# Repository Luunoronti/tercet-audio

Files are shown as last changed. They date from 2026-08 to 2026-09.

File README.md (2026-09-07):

# TERCET

Trzyczęściowy, w pełni analogowy lampowy tor audio DIY — trzy urządzenia
w spójnej serii (drewno + lustrzana stal nierdzewna + żarzenie lamp):

1. **`riaa/`** — przedwzmacniacz gramofonowy RIAA (stereo).
   2× ECC83 + ECC82 (wtórnik katodowy), pasywna korekcja 3180/318/75 µs,
   B+ rozdzielone per kanał, dławik w filtrze, automatyczne rozładowanie
   kondensatorów, wyciszanie wyjść z opóźnieniem, ground breaker GND/PE.
   **Stan: schemat rev E — gotowy do budowy.**
2. **`power-amp/`** — lampowa końcówka mocy z regulacją głośności
   i analogowymi wskaźnikami wychyłowymi. *Stan: planowanie.*
3. **`preamp/`** — przedwzmacniacz liniowy: selektor wejść, głośność,
   balans, mono, filtry, barwa. *Stan: planowanie.*

Poza serią: **`headamp/`** — lampowy wzmacniacz słuchawkowy SE EL84
pod DT 770 M (stan: schemat poglądowy + symulacje; patrz
`docs/PROJEKT-HEADAMP.md`).

Pozostałe katalogi: **`common/`** — bloki współdzielone między urządzeniami
(żarzenie DC z LD1085, automatyka rozładowania/mute), **`enclosure/`** —
pliki obudów (DXF płyt pod cięcie laserowe, grawer frontów),
**`docs/`** — dokument ustaleń projektu (`PROJEKT-RIAA.md` = "pamięć"
projektu; przy pracy z AI podawać ten plik na starcie sesji).

## Jak pracujemy z plikami KiCada

Schematy są **generowane skryptem**: `riaa/gen.py` (+ `symlib.py`) buduje
`riaa_preamp.kicad_sch` od zera, z symbolami osadzonymi w pliku (otwiera się
w KiCadzie 7+ bez zewnętrznych bibliotek). Weryfikacja: `check.py` eksportuje
netlistę przez `kicad-cli` i sprawdza ~60 asercji połączeń (w tym rozdział
masy sygnałowej od PE i separację kanałów).

```
cd riaa
python3 gen.py
kicad-cli sch export netlist -o riaa.net riaa_preamp.kicad_sch
python3 check.py
kicad-cli sch export pdf -o riaa_preamp.pdf riaa_preamp.kicad_sch
```

Zmiany koncepcyjne robimy w `gen.py` i regenerujemy; drobne poprawki ręczne
w Eeschema są OK, ale wtedy plik `.kicad_sch` staje się źródłem prawdy —
odnotować w commicie. Etap PCB: planowany interaktywnie przez wtyczkę
Konnect (KiCad 10 + MCP).

## Bezpieczeństwo

W urządzeniach występują napięcia do ~330 V DC — śmiertelnie niebezpieczne.
Zasady (PE, ground breaker, rozładowanie, pomiar przed pracą) opisane
w `docs/PROJEKT-RIAA.md` i na schematach. Budujesz na własną
odpowiedzialność.

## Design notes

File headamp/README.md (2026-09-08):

# headamp — lampowy wzmacniacz słuchawkowy (SE EL84)

Czwarte urządzenie serii (poza kanonicznym "tercetem"): biurkowy wzmacniacz
słuchawkowy pod Beyerdynamic DT 770 M (80 Ω), źródło: DAC (E-MU 0202 USB,
wyjście liniowe). W torze sygnałowym wyłącznie lampy i transformatory.

**Topologia (na kanał):** ½ ECC82 (wspólna katoda) → RC → EL84 w triodzie
(g2→a przez 100R) → transformator SE 5k:80 Ω. Bez globalnego NFB.
B+ ~300 V (CLC), żarzenie DC + elewacja +50 V — blok wspólny, patrz
`common/` (LD1085, identyczny jak w RIAA).

**Przełączniki charakteru (oba czysto pasywne):**
- **S1 (DPDT)** — crossfeed między DAC a potencjometrem: bas −14 dB do
  przeciwnego kanału, wygasa >~700 Hz; scena "z kolumn".
- **S2 (DPST)** — "wokal do przodu": odłącza C2b 100µ przy katodzie drivera
  (zostaje 1µ) → półka −3 dB poniżej ~200 Hz.

**Wyniki symulacji** (ngspice, modele Korena; `sim/`):
wzmocnienie 24,7 dB @1 kHz; pasmo −3 dB: 24 Hz…>100 kHz (dół ograniczony
Lp OPT=15 H — zamówić ≥25 H); Zout ~36 Ω; THD @0,6 Vrms: 0,20%
(niemal czysta H2, H3 −87 dB); EL84: 285 V / 29 mA (8,2 W).

Szczegóły i log decyzji: `docs/PROJEKT-HEADAMP.md`.

## Pliki
- `gen.py` — generator schematu KiCad (`headamp.kicad_sch`); **źródło
  prawdy jest w tym pliku, NIE edytować schematu ręcznie w Eeschema**
  (regeneracja go nadpisze). UUID deterministyczne (uuid5) — dwa
  uruchomienia dają identyczny plik. Layout w ramkach modułów (WEJŚCIE,
  KANAŁ L, KANAŁ P, WYJŚCIE, SIEĆ, ZASILACZ B+, ŻARZENIE); połączenia
  między modułami drutami (nie global_label), poza ELEV (etykieta
  lokalna, tam gdzie łączy dzielnik elewacji z blokiem żarzenia) i GND/PE
  (symbole power). Żarniki lamp (ECC82 U1 unit3, EL84 U2/U202 unit2)
  narysowane wewnątrz ramki ŻARZENIE, połączone drutami z wyjściem
  LD1085 i z minusem żarzenia (= ELEV).
- `symlib.py` — parser symboli KiCad (kopia `riaa/symlib.py`, inna
  ścieżka domyślna biblioteki: Windows).
- `check.py` — asercje netlisty (wzór `riaa/check.py`): kanał L, kanał
  P (funkcja `chan()` parametryzowana referencjami), zasilacz, crossfeed
  S1, gniazda WE/WY.
- `sim/amp.cir` — pełny tor (driver + końcówka + OPT), .op / .ac / THD
- `sim/crossfeed.cir` — sieć crossfeedu S1, wariant "ON" (bez przełącznika,
  same wartości R/C) - historyczny, poprzednik `crossfeed_sw.cir`.
- `sim/crossfeed_sw.cir` — **źródło prawdy** dla topologii narysowanej w
  `gen.py` (SW401 na WYJŚCIU galęzi krzyżowej, DECYZJA 2026-09-08 - patrz
  docs/PROJEKT-HEADAMP.md). Trzy warianty w jednym pliku (ngspice batch,
  kolejne `.end`): 1) ON (krzyżowy załączony), 2) OFF nowa topologia
  (S1 na wyjściu - odłącza całą galąź krzyżową od wyjść), 3) OFF stara
  topologia (S1 na wejściu, ODRZUCONA - R405/R406+C403/C404 nadal
  obciążają wyjścia, ugięcie basu ~1,4 dB - uzasadnienie zmiany).
- `ref/headamp.pdf` — eksport aktualnego schematu (`kicad-cli sch export
  pdf`), regenerowany po każdej zmianie i commitowany razem z
  `headamp.kicad_sch` (patrz Workflow niżej).
- `ref/se_el84.svg`, `ref/crossfeed.svg` — schematy poglądowe (schemdraw,
  historyczne, przed generatorem)
- `layout/layout_top.py` — generator (matplotlib, bez KiCada) propozycji
  **rozmieszczenia elementów w obudowie** (rzut z góry, 260×200 mm, skala
  1:1 — zmniejszone 2026-09-08 z pierwotnych 300×250, patrz
  docs/PROJEKT-HEADAMP.md) → `ref/layout_top.svg`/`.png`. Zasilacz na
  chassis (górnej płycie) tylko jako bryły T301/L1/J1+F1/SW1/NE1; reszta
  zasilacza na **PCB** (DECYZJA, nie powietrznie — patrz
  docs/PROJEKT-HEADAMP.md) w zarezerwowanej strefie pod płytą. Montaż
  powietrzny toru audio: listwy lutownicze + elementy na nóżkach
  podstawek lamp — szczegółowy przydział w `ref/layout_bom_montaz.md`.
- `ref/layout_bom_montaz.md` — tabela przydziału elementów toru audio:
  na nóżkach podstawek lamp vs listwy lutownicze A/B_L/B_P/D, z numerami
  pinów (ECC82/EL84) i uzasadnieniem.

## Projekt roboczy (edycja ręczna)
`kicad/headamp.kicad_pro` + `kicad/headamp.kicad_sch` — kopia schematu
wygenerowanego niżej (netlista równoważna, DECYZJA 2026-09-08), z
nowym uuid arkusza. To jest **plik roboczy edytowany ręcznie w Eeschema
przez użytkownika** (bez MCP Konnect); `gen.py`/`headamp.kicad_sch` w tym
katalogu (`headamp/`) to od teraz archiwalny pierwowzór, nie rozwijany
dalej. Workflow weryfikacji po edycji `kicad/headamp.kicad_sch`:
```
kicad-cli sch export netlist --format kicadsexpr -o headamp/kicad/headamp.net headamp/kicad/headamp.kicad_sch
python headamp/check.py headamp/kicad/headamp.net
kicad-cli sch erc --format json --severity-all -o headamp/kicad/erc.json headamp/kicad/headamp.kicad_sch
kicad-cli sch export pdf -o headamp/ref/headamp_kicad.pdf headamp/kicad/headamp.kicad_sch
```
Oczekiwane: check.py OK; ERC 0/0. Szczegóły: docs/PROJEKT-HEADAMP.md,
CLAUDE.md.

## Workflow (regeneracja schematu, archiwalne gen.py)
```
python headamp/gen.py
kicad-cli sch export netlist --format kicadsexpr -o headamp/headamp.net headamp/headamp.kicad_sch
python headamp/check.py
kicad-cli sch erc --format json --severity-all -o erc.json headamp/headamp.kicad_sch
kicad-cli sch export pdf -o headamp/ref/headamp.pdf headamp/headamp.kicad_sch
```
Oczekiwane: check.py OK; **ERC = 0 błędów, 0 ostrzeżeń**. Ostatni krok
(PDF do `headamp/ref/`) wykonać po każdej zmianie schematu i obejrzeć
wynik - `headamp/ref/headamp.pdf` jest commitowany razem z
`headamp.kicad_sch` (nie jest ignorowany, mimo że `.gitignore` wycina
`headamp/*.pdf` gdzie indziej). Szczegóły i log decyzji:
docs/PROJEKT-HEADAMP.md.

## Uruchomienie symulacji
```
cd headamp/sim
ngspice -b amp.cir
ngspice -b crossfeed_sw.cir
```

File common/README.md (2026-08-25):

# common — bloki współdzielone serii TERCET

Bloki projektowane z myślą o reużyciu we wszystkich trzech urządzeniach
(na razie opisane w schemacie RIAA; przy końcówce mocy wydzielimy je tu
jako wspólne moduły/PCB):

- **Żarzenie DC**: uzwojenie ~7 V → mostek Schottky (1N5822) → 10000 µF →
  LDO LD1085 → 6,3 V DC, z elewacją do +50 V (dzielnik z B+).
- **Automatyka**: K1 — rozładowanie kondensatorów po zaniku sieci
  (styk NC + rezystor mocy); K2/K3 — wyciszanie wyjść z opóźnieniem
  (2N7000 + RC), natychmiastowy mute przy wyłączeniu.
- **Ground breaker**: 10R/5W ∥ 2× 1N5408 antyrównolegle ∥ 100n —
  jedyny punkt styku masy sygnałowej z chassis/PE.
- **Wejście sieciowe**: IEC + bezpiecznik → wyłącznik DPST → NTC →
  transformator; warystor; neonówka jako kontrolka.

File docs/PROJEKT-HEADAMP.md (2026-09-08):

# PROJEKT-HEADAMP — pamięć projektu wzmacniacza słuchawkowego

Dokument ustaleń, analogicznie do PROJEKT-RIAA.md. Przy pracy z AI podawać
ten plik na starcie sesji.

## Słuchawki — rekomendacja (żeby nie zapomnieć)
Kryterium nadrzędne: **jak najsilniejsze pasywne tłumienie hałasu** (praca
w głośnym otoczeniu; test odniesienia: syrena centralki alarmowej ma być
znośna). Bez ANC.

1. **Beyerdynamic DT 770 M** — WYBÓR GŁÓWNY (pod niego projektowany
   wzmacniacz). Uwaga: koniecznie wersja **"M"** (monitoring, dla perkusistów),
   nie zwykłe DT 770 Pro! ~35 dBA tłumienia (najwięcej wśród nausznych),
   80 Ω, mocny docisk (cena izolacji). OPT 5k:80 dobrany pod tę impedancję.
2. **Sennheiser HD 280 Pro** — plan B / budżetowo: do 32 dB, 64 Ω,
   ~85% izolacji DT 770 M za mniej niż połowę ceny; brzmienie poprawne, suche.
3. **Etymotic ER2SE / ER4SR (douszne + pianki)** — najlepsza izolacja
   w ogóle (35–42 dB) i wzorcowa neutralność, jeśli douszne wchodzą w grę;
   niska impedancja/wysoka czułość — uwaga na szum i dobór odczepu OPT.
Odrzucone: Direct Sound EX-29, Vic Firth SIH2 (izolacja OK, dźwięk słaby).

## Kontekst i wymagania
- Słuchawki: **Beyerdynamic DT 770 M** (80 Ω) — wybrane za najsilniejsze
  pasywne tłumienie hałasu wśród nausznych (~35 dBA); jeszcze nie kupione.
- Źródło: komputer w pracy → **E-MU 0202 USB** jako DAC (wyjście liniowe;
  sekcja słuchawkowa 0202 nieużywana — 22 Ω wyjścia, 16 mW).
  Odtwarzanie: lossless, tryb WASAPI Exclusive/ASIO, głośność 100%.
- Cel brzmieniowy: **lampowe ciepło** (dominacja H2), **dobra scena**,
  **wyraźny wokal** (możliwość uwypuklenia).
- Wymóg: w torze audio **zero półprzewodników** (krzem tylko w zasilaczu).
- Docelowo praca na biurku; bezpieczeństwo jak w RIAA (~300 V!).

## Topologia (DECYZJA)
Na kanał: ½ ECC82 wspólna katoda → sprzężenie RC → EL84 w trybie triodowym
(g2→anoda przez 100R) → transformator wyjściowy SE 5k:80 Ω.
- Odrzucone: OTL (Zout za wysokie przy 80 Ω), hybryda lampa+MOSFET
  (półprzewodnik w torze), White follower (projekt "na później").
- **Bez globalnego NFB** — świadomie: pełny profil H2, brak ryzyka
  niestabilności z OPT w pętli. Opcja na przyszłość: przełączane ~6 dB
  (Zout →~16 Ω, THD /2, gain −6 dB).

## Wartości (punkt startowy, zweryfikowany symulacją)
Driver: Ra 47k/2W, Rk 1k5 + C 100µ (patrz S2), grid leak 470k, stopper 1k,
odsprzęganie B+ drivera 10k/2W + 47µ/350V. Sprzężenie 100n/400V, grid leak
EL84 470k, stopper 1k. EL84: Rk 270R/5W + 470µ/25V, zwora g2 100R.
OPT: SE 5k:80, szczelina, ≥45 mA DC, **Lp ≥ 25 H** (symulowane 15 H daje
dół −3 dB @24 Hz — zamówić większą indukcyjność), rozproszenie ≤10 mH.
Zasilanie: 230→250 V, mostek UF4007, 220µ + dławik 5–10 H + 220µ, B+ ~300 V.
Żarzenie: blok z `common/` (Schottky → 10000µ → LD1085 → 6,3 V DC,
elewacja +50 V z dzielnika B+ 220k/47k + 10µ). Budżet: 2×EL84 + ECC82 ≈1,9 A.

## Przełączniki charakteru (obie funkcje pasywne, DECYZJA)
- **S1 crossfeed (DPDT)**, między gniazdami wejściowymi a potencjometrem.
  Wartości po strojeniu w ngspice: tor prosty R 1k ∥ C 470n; krzyżowy
  R 2k2 → C 220n do masy → R 3k3 do przeciwnego kanału. Efekt: przesłuch
  −14 dB w basie, wygasa >~700 Hz; strata wtrąceniowa ~1–3 dB (skok
  głośności przy przełączaniu — normalny). Tor prosty (R401∥C401/
  R402∥C402) jest ZAWSZE wpięty (bypass przełącznika) - to się nie
  zmieniło. **Implementacja na schemacie - przełącznik po stronie
  WYJŚCIOWEJ galęzi krzyżowej (DECYZJA 2026-09-08, patrz "Decyzje -
  crossfeed S1 na wyjściu" niżej dla pełnego uzasadnienia i liczb z
  symulacji)** - `sim/crossfeed_sw.cir` jest źródłem prawdy dla dokładnej
  topologii (trzy warianty: ON, OFF nowa topologia, OFF stara topologia -
  porównanie).
- **S2 "wokal do przodu" (DPST, po sekcji na kanał)**: katoda drivera ma
  C2a 1µ na stałe + C2b 100µ dołączane przełącznikiem. S2 otwarty →
  półka −3 dB poniżej ~200 Hz (lokalna degeneracja katodowa), wokal
  na pierwszym planie. Niskie napięcie (~4 V) — dowolny mały przełącznik.

## Wyniki symulacji (ngspice, modele Korena; headamp/sim/)
- Punkt pracy: EL84 285 V a-k / 29 mA (8,2 W z 12 W max); driver 140 V / 2,8 mA.
- Wzmocnienie 24,7 dB @1 kHz (ogromny zapas przy 2 Vrms z DAC).
- Pasmo (Lp=15 H): −3 dB @ 24 Hz i >100 kHz; Zout ~36 Ω (DF~2,2 przy 80 Ω).
- THD 1 kHz: 0,6 Vrms → 0,20% / 1,8 Vrms → 0,59% / 5,3 Vrms → 1,84%;
  widmo zdominowane przez H2 (H3 niżej o 20–33 dB) — profil "ciepły".
- Zastrzeżenie: modele Korena wiarygodne co do trendu, nie co do setnych %.

## Narzędzia / workflow (DECYZJA)
- KiCad 10; schemat docelowo generowany skryptem jak `riaa/gen.py` — TODO.
- MCP: wtyczka **Konnect** (github.com/mixelpixx/Konnect, beta, AGPL —
  darmowa dla hobbysty; PCM install + wpis w konfigu Claude Desktop).
- Symulacje: ngspice (netlisty w `headamp/sim/`).

## TODO (patrz tez aktualna lista na koncu dokumentu, po Etapie 5b)
1. Zakup DT 770 M; sprawdzić sterowniki 0202 pod Windows na maszynie roboczej.
2. Specyfikacja OPT dla nawijacza (5k:80, ≥45 mA, Lp ≥25 H, opc. odczepy
   32/300 Ω) + wycena (Ogonowski / Trafco itp.).
3. ~~`headamp/gen.py` + `check.py` (asercje netlisty jak w RIAA).~~ ZROBIONE.
4. BOM z symbolami TME; przenieść blok żarzenia z `common/` 1:1.
5. ~~Rozładowanie B+ (220k/2W przez C11) — przejąć automatykę K1 z common.~~
   ZROBIONE (Etap 5b: R303 bleeder + K1/R306).
6. Decyzja obudowy: wpisać w serię TERCET (drewno + stal + widoczne lampy).

## Decyzje - Etap 5a (kanal P, 2026-09-07)
- RV1 = **potencjometr podwojny** (jedna fizyczna os), symbol
  `Device:R_Potentiometer_Dual_Separate` (biblioteka systemowa KiCad 10):
  unit 1 (piny 1/2/3) = kanal L, unit 2 (piny 4/5/6, identyczna geometria
  wzgledna) = kanal P. Brak wczesniejszej decyzji w tym dokumencie -
  wybrano zamiast dwoch osobnych RV1A/RV1B, bo w bibliotece jest gotowy
  symbol dual, a w praktyce kupujemy jeden fizyczny podwojny potencjometr
  (Alps/inny), nie dwa osobne.
- Kanal P: refy +200 wzgledem kanalu L (R201-R209, C201-C206, SW202,
  T201, U202=drugi EL84); U1 (ECC82) unit B (piny 1=A,2=G,3=K) dla
  drivera kanalu P - ta sama fizyczna lampa co kanal L. Etykiety
  IN_R/OUT_R (nie IN_P/OUT_P - zgodnie z konwencja L/R jak w RIAA).
- Layout: kanal P = identyczna geometria kanalu L, przesunieta o
  dy=105,41 mm w Y (wielokrotnosc siatki 1,27 mm - inna wartosc daje
  ERC "endpoint_off_grid" na kazdym przesunietym drucie/pinie).
- Grzanie: wspolna szyna HEAT_A/HEAT_B dla wszystkich 3 lamp (ECC82
  U1 unit F, EL84 U2 i U202, kazdy wlasny unit grzania) - jak w RIAA.
- PWR_FLAG na powrocie wtornym OPT do GND: tylko JEDEN na cala plansze
  (przy T1/kanal L) - drugi (na T201/kanal P) daje ERC error "Power
  output and Power output are connected" (oba na tym samym wezle GND).
- Paper: na razie zostaje **A3** (kanal P miesci sie, max Y ~275 mm);
  decyzja o A2 odlozona do Etapu 5b (zasilacz), patrz TODO.

## Decyzje - Etap 5b (zasilacz, 2026-09-07)
- Zasilacz narysowany na tym samym arkuszu co audio (nie osobny arkusz
  hierarchiczny), layout DRUTAMI jak riaa/gen.py, pod kanalem P i
  grzaniem lamp. Numeracja 3xx (R301.., C301.., D301..), z wyjatkami
  nazwanymi wprost (F1, SW1, J1, RT1, RV301, NE1, T301, L1, K1, U301) -
  zgodnie z poleceniem etapu.
- **Paper zmieniony z A3 na A2** (DECYZJA) - zasilacz + oba kanaly +
  grzanie nie miesciy sie w A3 (docelowa wysokosc tresci ~427mm).
- **B+ (+300V) WSPOLNY dla obu kanalow** (bez podzialu per-kanal jak w
  RIAA) - headamp ma mniejszy pobor pradu (2x EL84 + ECC82, bez
  wtornika mocy), jeden wezel +300V po filtrze CLC wystarcza; brak
  osobnych R/C dropperow per kanal.
- Transformator: `Device:Transformer_1P_2S` (2 uzwojenia wtorne - HT +
  zarzenie), NIE customowy symbol jak w RIAA (headamp nie potrzebuje
  uzwojenia 24V rezerwowego ani odczepu 6,3V - tylko jedno uzwojenie
  zarzenia 7V/3A na 3 lampy, patrz common/README.md).
  Wartosc pola Value: "EI84 100VA: 230V : 250V/0,15A + 7V/3A".
- Mostek HT: 4x UF4007 + snubber RC 470R/10n-1kV przez uzwojenie (1:1
  z riaa/common). Filtr: C 220u/400V -> L1 (dlawik, etykieta wartosci
  "5-10H 100mA", uwaga: Lp OPT >=25H to co innego - dlawik zasilacza
  nie ma zwiazku z indukcyjnoscia pierwotna OPT) -> C 220u/400V = +300V.
  Bleeder 220k/2W (R303) na wyjsciu (zamyka TODO 5 z listy glownej).
- Elewacja zarzenia: 220k (R304, z +300V) -> ELEV -> 47k (R305) -> GND;
  10u/100V (C304) ELEV->GND. Wartosci z PROJEKT-HEADAMP (220k/47k),
  NIE z RIAA (470k/100k) - inny prad/napiecie docelowe (+50V dla 6,3V
  vs RIAA gdzie wtornik ma Vhk wiekszy).
- Rozladowanie K1: 1:1 z riaa/common (przekaznik 9V cewka V_RAW/ELEV,
  dioda 1N4007 gaszaca, styk NC(11-12) -> R306 4k7/10W -> GND, COM(12)
  na +300V, NO(14) niepodlaczony).
- Zarzenie: 7V -> 4x 1N5822 -> 10000u/16V (=V_RAW) -> 470u/25V ->
  LD1085 (symbol Regulator_Linear:LM317_TO-220, adnotacja "LD1085
  (LDO)") -> 240R/976R -> 6,3V DC (HEAT_A/HEAT_B), 10u/25V + 1u
  odsprzegajace. Wartosci identyczne jak common/riaa.
- PWR_FLAG: zasada "jeden na siec" - usuniete zdublowane flagi (HEAT_A
  ma juz sterownik U301.VO, drugi punkt zwarty do GND przez OPT
  sekundarny nie potrzebuje wlasnej flagi skoro siec GND ma juz inna).
  Dodana 1 nowa flaga na V_RAW (mostek Schottky to elementy bierne,
  ERC wymaga sterownika dla U301.VI).
- ERC: multiple_net_names ELEV/HEAT_B (heater powrot zwarty do ELEV,
  jak w common/riaa) - OSTRZEZENIE OCZEKIWANE, zaakceptowane zgodnie
  z poleceniem etapu.
- Ground breaker: 1:1 z common/riaa (10R/5W + 2x1N5408 antyrownolegle
  + 100n/630V), jedyny styk masy sygnalowej (GND) z PE/chassis.

## Stan realizacji (2026-09-08, po kosmetyce arkusza)
- Schemat generowany skryptem **`headamp/gen.py`** (+ `symlib.py` +
  `check.py`, wzor riaa/) - **zrodlo prawdy = gen.py, NIE edytowac
  `headamp.kicad_sch` recznie**. UUID deterministyczne (uuid5) -
  regeneracja jest idempotentna (git diff pusty przy dwoch uruchomieniach).
- Kanał L + kanał P + zasilacz + crossfeed S1 + gniazda WE/WY + żarniki
  lamp **kompletne, layout w ramkach modułów**. **ERC: 0 błędów, 0
  ostrzeżeń** (po przywróceniu żarników drutami - patrz "Decyzje -
  kosmetyka arkusza" niżej). Na schemacie zostały wyłącznie symbole GND -
  ELEV/V_RAW poprowadzone drutami, PE bez symbolu `Earth_Protective`,
  PWR_FLAG zredukowane do 3 (empirycznie sprawdzone) - patrz "Decyzja -
  tylko GND jako symbol" niżej.
- UWAGA numeracja na schemacie różni się od sekcji "Wartości" wyżej:
  C2=1µ (katoda, stały), C3=100µ (za SW2), C5=100n (sprzęgający),
  C6=470µ (katoda EL84), R9=100R (zwora triodowa) - kanał L; kanał P =
  te same refy +200; moduł wejściowy (crossfeed+gniazda) = refy 4xx
  (J401/J402/J403, SW401, R401-R406, C401-C404). Schemat (gen.py) =
  źródło prawdy.
- Tolerancje (pole `Tolerance`, widoczne pod Value; DECYZJA): rezystory 5%
  (R3 1k5 katoda drivera — 1%, punkt pracy), folie C1/C5 5%, elektrolity
  20%, RV1 20%. Lampy/OPT/przełączniki bez tolerancji. Zaimplementowane
  w gen.py (parametr `tol=` w `place()`).
- Kanał P (Etap 5a): unit B ECC82 (driver), drugi EL84 (U202), drugi OPT
  (T201), RV1 = potencjometr podwójny. Layout = geometria kanału L
  przesunięta w Y (dy=105,41mm, siatka 1,27mm).
- Zasilacz (Etap 5b): B+ wspólny 300V (CLC), elewacja 220k/47k, K1
  rozładowanie, żarzenie LD1085, ground breaker - patrz sekcja DECYZJE
  wyżej.
- Crossfeed S1 + gniazda WE/WY (Etap 6/A-B): narysowane w gen.py, wg
  `sim/crossfeed.cir` - patrz "Decyzje - Etap 6" wyżej dla pełnego opisu.
- Layout w ramkach modułów + hybryda "druty zamiast etykiet" dla B+
  (Etap 6/A) - patrz "Decyzje - Etap 6".
- Kolejne kroki i stan narzędzi (Konnect/KiCad): patrz CLAUDE.md w korzeniu.
- **DECYZJA 2026-09-08: nowy projekt `headamp/kicad/headamp.kicad_pro` +
  `headamp.kicad_sch`** do dalszej edycji ręcznej w Eeschema. Kopia
  schematu z `gen.py` (ta sama treść `.kicad_sch`, format 20231120), z
  NOWYM uuid arkusza (uuid4) - podmienione konsekwentnie w header i we
  wszystkich blokach `instances`, żeby referencje (R1, U1...) nie
  zgubiły przypisania. `.kicad_pro` minimalny jak pierwotny (7 pól: board,
  libraries, meta, sheets [[uuid, "Root"]], text_variables) - bez tablic
  bibliotek (symbole są osadzone w `lib_symbols`). Weryfikacja: netlista
  nowego pliku programowo porównana ze starym - identyczna partycja par
  (ref,pin) na sieciach (58 sieci, 0 różnic; nazwy sieci auto pominięte w
  porównaniu, bo schemat nie ma etykiet nazwanych netów); `check.py`
  (rozszerzone o opcjonalny argument ścieżki netlisty, domyślnie stara)
  OK na obu; ERC nowego pliku 0 błędów/0 ostrzeżeń; PDF wyeksportowany do
  `headamp/ref/headamp_kicad.pdf`. Od teraz **`headamp/kicad/headamp.kicad_sch`
  = plik roboczy edytowany ręcznie w Eeschema przez użytkownika** (zmiany
  przez Claude tylko bezpośrednią edycją pliku/skryptami, BEZ MCP
  Konnect); **`headamp/gen.py` + `headamp/headamp.kicad_sch` = archiwalny
  pierwowzór (stan 2026-09-08), nie rozwijany dalej**. `.gitignore` nie
  wymagał zmian - istniejące wzorce (`*.kicad_prl`, `*-backups/`,
  `_autosave-*`, `*.lck`, `fp-info-cache`) łapią też artefakty w
  `headamp/kicad/` (zweryfikowane `git check-ignore -v`). Workflow
  weryfikacji po edycji: patrz `headamp/README.md` / CLAUDE.md.

## TODO (aktualizacja po kosmetyce arkusza - skreslone zrobione)
- ~~gen.py + check.py (kanał L port 1:1)~~ ZROBIONE (Etap 0-1).
- ~~Kanał P~~ ZROBIONE (Etap 5a).
- ~~Zasilacz (B+, żarzenie, K1, ground breaker)~~ ZROBIONE (Etap 5b).
- ~~Crossfeed S1 (DPDT) + gniazda WE/WY na schemacie~~ ZROBIONE (Etap
  6/A-B, patrz sekcja "Decyzje - Etap 6" niżej).
- ~~Estetyka schematu (Etap 6)~~ ZROBIONE (przegląd render -> poprawki
  pól ref/value/tolerance w gen.py: domyślne offsety 3-liniowe, F1/SW1,
  J1/PWR_FLAG/Earth_Protective, R301/NE1, R303/L1, ground breaker).
- ~~ERC `missing_power_pin` (3 błędy, U1/U2/U202)~~ ZAŁATWIONE (2026-09-08,
  wariant a): żarniki lamp przywrócone na schemat, rysowane drutami
  wewnątrz ramki ŻARZENIE - patrz "Decyzje - kosmetyka arkusza" niżej.
  ERC = 0 błędów, 0 ostrzeżeń.
- BOM (TME) + specyfikacja OPT dla nawijacza (5k:80, ≥45mA, Lp≥25H).
- Zakup DT 770 M; sprawdzić sterowniki 0202 pod Windows.
- Decyzja obudowy (seria TERCET).

## Decyzje - Etap 6 (layout w ramkach, crossfeed, gniazda, 2026-09-08)

**A. Hybryda "druty zamiast etykiet".** Połączenia MIĘDZY modułami
(B+ → oba kanały i OPT, sygnał wejście → crossfeed → RV1 → kanały,
wyjścia OPT → gniazdo słuchawkowe) są teraz rysowane prawdziwymi drutami
(z junctions), bez global/local labels - poza HEAT_A/HEAT_B i ELEV,
które explicite zostają etykietami (patrz punkt B) i GND/PE, które
zostają symbolami power (fizycznie szyna masy), zgodnie z konwencją
common/riaa. B+ (+300V): jedna magistrala pionowa `BUS_X=245,11mm`
(`headamp/gen.py`) łącząca korytarze nad oboma kanałami (y=80,01/185,42,
powyżej wszystkich komponentów kanału - brak kolizji) z zasilaczem (CLC,
R304/elewacja, K1) - zamiast 7 wcześniejszych `global_label('+300V')`.

**B. Żarniki lamp NIE SĄ RYSOWANE (DECYZJA).** Unity grzania ECC82 (U1
unit3), EL84 audio L/P (U2/U202 unit2) usunięte ze schematu razem z
drutami i etykietami po stronie lamp (dawny "rząd grzania" pod kanałem
P, Etap 5a). Blok zasilacza (LD1085/U301) kończy się jak wcześniej
etykietami lokalnymi **HEAT_A** (+6,3 V) i **HEAT_B** (= ELEV, minus
żarzenia, stąd oczekiwane ostrzeżenie ERC `multiple_net_names`) na
końcach drutów, z adnotacją tekstową na schemacie (obok U301):
"Zarzenie do lamp (skrecona para): ECC82 piny 4+5 -> HEAT_A, pin 9 ->
HEAT_B; EL84 (x2) pin 4 -> HEAT_A, pin 5 -> HEAT_B." - montażysta
łączy żarniki punkt-punkt wg tego opisu, nie wg schematu.
**Konsekwencja odkryta w tym etapie (różni się od pierwotnego briefu):**
piny grzania w bibliotece `Valve` (ECC81 unit C, EL84 unit B) są typu
`power_in`. KiCad ERC dla unitu z pinami `power_in`, który w ogóle nie
jest umieszczony na schemacie, zgłasza nie tylko ostrzeżenie
`missing_unit` (przewidziane), ale też **błąd `missing_power_pin`** (dla
każdego z U1/U2/U202 - 3 błędy). Domyślna severity tej reguły
(`error`) jest zapisana w `headamp.kicad_pro`
(`erc/rule_severities/missing_power_pin`), pliku poza zakresem zmian
generatora (nie ruszać/nie commitować - patrz CLAUDE.md) - nie da się
więc obniżyć jej z poziomu `gen.py`/`check.py`. Efekt: ERC schematu ma
formalnie 3 błędy, nie tylko same ostrzeżenia. Zaakceptowane jako
świadoma, udokumentowana konsekwencja decyzji "żarniki nie są rysowane"
- alternatywa (przywrócenie unitów z realnym okablowaniem) cofnęłaby tę
decyzję i wymaga wyraźnego wyboru użytkownika (patrz TODO wyżej).

**C. Crossfeed S1 - przełączany DPDT.** ***UWAGA: topologia opisana w tym
punkcie (przełącznik po stronie WEJŚCIOWEJ galęzi krzyżowej) została
ZASTĄPIONA decyzją z 2026-09-08 - patrz sekcja "Decyzje - crossfeed S1 na
wyjściu (2026-09-08)" na końcu dokumentu. Punkt C zostaje jako zapis
historyczny (uzasadnienie zmiany, liczby z porównania).*** Element `SW401`
(`Switch:SW_DPDT_x2`), Value "S1 crossfeed", numeracja 4xx (moduł
wejściowy: J401/J402, SW401, R401-R406, C401-C404). **Topologia i
wartości - ŹRÓDŁO PRAWDY: `headamp/sim/crossfeed.cir`** (nie opis niżej
w tym dokumencie sprzed Etapu 6, ani wcześniejsza wersja - cir nie
zawiera samego przełącznika, modeluje topologię z pozycją "krzyżowy"
załączoną). Implementacja: tor prosty R401∥C401 (kanał L), R402∥C402
(kanał P) jest **ZAWSZE wpięty** między gniazdo a RV1 (bypass
przełącznika - w cir to węzły `l1->lout`/`r1->rout`, obecne bez
przełącznika w ogóle). SW401 przełącza **tylko dopływ sygnału do gałęzi
krzyżowej**: pole 1 (piny 1/2, unit1) doprowadza IN_L do R403; pole 2
(piny 4/5, unit2) doprowadza IN_R do R404; trzeci pin każdego pola (3/6)
jest NC - to reprezentuje pozycję "prosty" (gałąź krzyżowa odłączona,
pływająca). Gałąź krzyżowa: R403(2k2) SW->mL, C403(220n) mL->GND,
R405(3k3) mL->outR (przeciwny kanał); mirror: R404/mR/C404/R406->outL.
Pozycji przełącznika (obu) nie da się zweryfikować statyczną netlistą -
schemat rysuje jedną (załączoną) pozycję, jak w cir; `check.py` sprawdza
to co da się sprawdzić statycznie (patrz komentarz w pliku).

**D. Gniazda WE/WY.** Wejście: 2× RCA `Connector:Conn_Coaxial` - J401
(IN L), J402 (IN R); pin sygnału -> crossfeed, ekran -> GND. Wyjście:
TRS 6,3 mm `Connector_Audio:AudioJack3` - J403; piny T=kanał L (T1
wtórne), R=kanał P (T201 wtórne), S=GND (wspólna z wtórnymi OPT).

**E. Layout w ramkach.** Moduły w ramkach (`(rectangle ...)` na
arkuszu, obsługiwane w formacie 20231120 - zweryfikowane) z tytułem w
lewym górnym rogu: WEJŚCIE, KANAŁ L, KANAŁ P, WYJŚCIE, SIEĆ 230V,
ZASILACZ B+ 300V, ŻARZENIE. Rozmieszczenie: lewo-góra WEJŚCIE;
KANAŁ L nad KANAŁ P (środek, ta sama geometria + dy); WYJŚCIE na prawo
od kanałów, między nimi w Y; dół (cała szerokość): SIEĆ | ZASILACZ B+ |
ŻARZENIE.

**F. Rozmiar arkusza: A2 zostaje** (DECYZJA, potwierdzona 2026-09-08 przy
kosmetyce arkusza - patrz niżej). Treść po Etapie 6 zajmowała ok.
400×428 mm (blisko górnej granicy A2 w orientacji poziomej, 594×420mm).
A3 (420×297) odpadał z powodu wysokości treści (428 mm > 297 mm)
niezależnie od szerokości, i nadal odpada po zmniejszeniu `PSU_DY` (patrz
"Decyzje - kosmetyka arkusza" niżej): treść ma teraz ok. 378 mm wysokości
- dalej ponad limit A3 (297 mm) o ~80 mm, więc A2 zostaje.

## Decyzje - kosmetyka arkusza (2026-09-08)

**G. Żarniki lamp przywrócone (wariant a).** Decyzja z Etapu 6 ("żarniki
nie są rysowane", ERC z 3 błędami `missing_power_pin`) COFNIĘTA na
wyraźne życzenie użytkownika. Unity grzania ECC82 (U1 unit3, piny 4/5/9)
i EL84 audio L/P (U2/U202 unit2, piny 4/5) są teraz narysowane WEWNĄTRZ
ramki „ŻARZENIE 6,3V DC", połączone **drutami** (nie etykietami) z
wyjściem VO regulatora LD1085 (U301, szyna „+6,3V" na wysokości `YHP`) i
z minusem żarzenia (szyna na wysokości `YHM`, ta sama sieć co ELEV).
Etykiety `HEAT_A`/`HEAT_B` oraz opisowy tekst z mapowaniem pinów
usunięte - teraz widać połączenia bezpośrednio na rysunku. Topologia:
ECC82 piny 4 i 5 (oba nazwane `F1` w symbolu, dwa końce żarnika) → +6,3V;
pin 9 (`F2`, środkowy odczep) → minus (redukcja przydźwięku, zgodnie z
zaleceniem). EL84: pin 4 (`F1`) → +6,3V; pin 5 (`F2`) → minus. Wszystkie
piny każdej lampy „zbiegają się" na wspólnej linii bazowej w połowie
odległości między szynami (`Y_HEAT_PINS = (YHP+YHM)/2`) i stamtąd
rozchodzą się w przeciwne strony (+ w górę, − w dół) - dzięki temu żaden
odcinek drutu nie nakłada się na inny (kluczowe dla ECC82, gdzie pin
środkowy `9` siedzi geometrycznie między pinami `4` i `5`). Krótki tekst
na schemacie: "Zarzenie do lamp: skrecona para, minus = ELEV (+53V)."
Ramka ŻARZENIE poszerzona (x1: 400→495,3mm), żeby pomieścić 3 lampy w
rzędzie (rozstaw 30,48/29,21mm - konwencja z wcześniejszej wersji
rysunku, commit fc227e8). **Efekt: ERC = 0 błędów, 0 ostrzeżeń**
(zniknęły `missing_unit` x3 i `missing_power_pin` x3; `multiple_net_names`
ELEV/HEAT_B też zniknęło, bo etykieta `HEAT_B` na końcu szyny została
usunięta - jedyna nazwa na tej sieci to teraz `ELEV`). check.py: dodane
asercje `same`/`diff` dla żarników po stronie lamp (U1.4/U1.5/U1.9,
U2.4/U2.5, U202.4/U202.5) w sekcji "zarzenia (grzanie)".

**H. Prąd żarzenia poprawiony: 1,7 A, nie 0,3 A.** Błąd merytoryczny w
tekście na schemacie ("ok. 0,3A z uzwojenia 7V (3 lampy)") - to była
literówka/nieporozumienie, prawidłowa wartość to **ok. 1,7 A** (2×EL84 ≈
0,76 A każda + ECC82 ≈ 0,15 A na obie połówki; budżet w tym dokumencie
to ≈1,9 A, patrz sekcja "Wartości" wyżej). Tekst poprawiony na: "Zarzenie:
6,3V DC / ok. 1,7A (2x EL84 0,76A + ECC82 0,15A; budzet 1,9A) z
uzwojenia 7V/3A." Inne liczby na schemacie/w dokumentacji sprawdzone przy
okazji (bez zmian, uznane za spójne):
- Uzwojenie żarzenia 7V/3A (T301) - zapas przy 1,7 A poboru, OK.
- B+ ~300V @ ~65mA (dokumentacja, nie schemat) - zgodne z symulacją
  (2×29mA EL84 + 2×2,8mA driver ≈ 63,6mA ≈ "~65mA").
- LD1085 3A - z dużym zapasem ponad 1,7A wymagane.
- Dropout LD1085 przy 1,7A: uzwojenie 7V AC -> mostek Schottky 1N5822 ->
  V_RAW (peak ~7×1,41−2×~0,5≈8,9V, pod obciążeniem realnie kilka mV/V
  mniej z tętnieniem) - z zapasem pokrywa Vout(6,3V)+dropout LD1085
  (typowo ~1,3-1,5V przy tym prądzie); tekst na schemacie zaktualizowany
  na "LD1085 (LDO) - LM317 ma za duzy dropout przy 1,7A (V_RAW ~9V z
  uzwojenia 7V wystarcza)." Zastrzeżenie: nie zmierzone na prototypie,
  wartość orientacyjna z danych katalogowych.

**I. Pusty pas między KANAŁ P a rzędem zasilacza zamknięty.** Między
ramką KANAŁ P (kończy się Y=282,41mm) a rzędem SIEC/ZASILACZ/ŻARZENIE
(zaczynał się Y=340mm) był pusty pas ~57,6mm. `PSU_DY` (przesunięcie
całego bloku zasilacza w Y) zmniejszony z 76,2mm do 26,67mm (SHIFT =
49,53mm = 39×1,27mm - wielokrotność siatki schematu, żeby wszystko
zostało na gridzie). Nowy pas ~8mm, jak między innymi modułami na
arkuszu. Współrzędne zapisane wcześniej jako już-wyliczone wartości
absolutne (nie "baza + PSU_DY": pola ref/value F1/R301/NE1/R309/D310/
D311/C309, kilka punktów drutów mostka HT/żarzenia) zostały ręcznie
przeliczone o ten sam SHIFT - reszta bloku (`LR`/`NR`/`YP`/`YM`/`YHP`/
`YHM` i wszystko wyrażone przez `PSU_DY`) przesunęła się automatycznie.
Zweryfikowane: regeneracja idempotentna (dwa uruchomienia `gen.py` dają
identyczny plik), ERC = 0/0, cała treść arkusza mieści się wygodnie w
obrębie ramki A2 (marginesy zachowane, nic nie dotyka ramki arkusza ani
tabliczki tytułowej - sprawdzone na renderze PDF w powiększeniu).

## Decyzje - crossfeed S1 na wyjściu (2026-09-08)

**Powód zmiany.** W topologii z Etapu 6 (SW401 na WEJŚCIU galęzi
krzyżowej - patrz punkt C wyżej) rezystory R405/R406 (3k3) i kondensatory
C403/C404 (220n) galęzi krzyżowej ZOSTAWAŁY na wyjściach nawet przy S1
w pozycji "prosty" (OFF): przełącznik odcinał tylko dopływ z wejścia do
R403/R404, ale R405+C403 (R406+C404) nadal wisiały jako obciążenie RC na
wyjściach toru prostego. Zmierzone symulacją (patrz niżej): ugięcie
pasma ~1,4 dB w rejonie 100-200 Hz - słyszalne, niepożądane przy "S1
OFF" (tor prosty powinien być dokładnie płaski). DECYZJA: przenieść S1
na stronę WYJŚCIOWĄ galęzi krzyżowej (za R405/R406, tuż przed wspólnym
węzłem z torem prostym) - przy S1 OFF cała galąź krzyżowa (R403..R406,
C403/C404) jest odcięta od wyjść, więc nie ma żadnego wpływu na tor
prosty.

**Symulacja (ngspice NIEDOSTĘPNY w PATH - nie zainstalowany, zgodnie z
poleceniem "jeśli nie - zgłoś, nie instaluj" NIE zainstalowano go; wyniki
niżej policzone analitycznie - nodal/MNA solver dla dokładnie tej samej
topologii RLC co w `sim/crossfeed_sw.cir`, skrypt jednorazowy, nie
commitowany). Plik `headamp/sim/crossfeed_sw.cir` zawiera 3 warianty
gotowe do uruchomienia w ngspice, gdy będzie dostępny (`ngspice -b
headamp/sim/crossfeed_sw.cir`):**

1. **ON (krzyżowy załączony)** - identyczny elektrycznie w obu
   topologiach (pozycja przełącznika nie zmienia, gdzie w torze siedzi,
   tylko czy jest zamknięty). Przesłuch (poziom na wyjściu
   przeciwnego kanału, sygnał testowy tylko w L): **-15,8 dB @100 Hz,
   -30,0 dB @1 kHz** (zanika >~700 Hz, zgodnie z wcześniejszym opisem
   "-14 dB w basie" - różnica rzędu 1-2 dB wobec wcześniejszego zapisu to
   normalna rozbieżność modelu, rząd wielkości ten sam).
2. **OFF, nowa topologia (S1 na wyjściu galęzi krzyżowej)** - odchyłka
   odpowiedzi kanału prostego (20 Hz-20 kHz) od płaskiej: **~0,17 dB**
   (od -0,19 dB @20 Hz do -0,02 dB @20 kHz) - to wyłącznie efekt C401/
   C402 (470n) w torze prostym (nie samego dzielnika R401/RpotL, który
   sam w sobie byłby idealnie płaski); brak przesłuchu (kanały całkowicie
   rozłączone, cross = -∞ dB w modelu).
3. **OFF, stara topologia (S1 na wejściu galęzi krzyżowej, ODRZUCONA)** -
   odpowiedź kanału prostego NIE jest płaska: dołek ok. **-1,58 dB w
   okolicy 200 Hz** względem końców pasma (-0,23 dB @20 Hz, -0,28 dB
   @20 kHz) - efekt obciążenia wyjścia przez R405 (3k3) szeregowo z C403
   (220n) do masy, mimo otwartego S1. Rozstęp całkowity ~1,36 dB - to
   właśnie "ugięcie basu" uzasadniające zmianę topologii.

**Zmiany w `headamp/gen.py` (moduł WEJŚCIE).** SW401 przeniesiony z
x=90,17 (przy wejściach) na x=149,86 (tuż przed magistralami wyjściowymi
outL/outR, x=175,26/185,42), obie sekcje (unit1/unit2) w tym samym x,
różne y (39,37 i 52,07) - "obok siebie". Element umieszczony z
`mirror='y'`, żeby COM (wspólny) wypadł po PRAWEJ (do wyjścia), a styk
(od strony R405/R406) po LEWEJ - odzwierciedla kierunek sygnału.
Wejścia J401/J402 podłączone teraz WPROST do R403/R404 (galąź krzyżowa)
i - osobnym odgałęzieniem nad/pod galęzią krzyżową (y=22,86 / y=64,77) -
do R401/R402 (tor prosty); przełącznik nie leży już na tej ścieżce.
R405/R406 łączą się ze stykiem SW401 (piny 1/4), NC (piny 3/6) pozostaje
jak wcześniej ("pozycja prosty = galąź pływająca"), COM (piny 2/5)
podłączony do magistrali wyjściowej przeciwnego kanału (sekcja A -> outR/
RV1.4, sekcja B -> outL/RV1.1). Layout "X" bez przecięcia drutów: galąź
L->P kończy na dalszej (prawej) magistrali outR, galąź P->L na bliższej
(lewej) magistrali outL - dwie przeciwbieżne ścieżki między rzędami L
(u góry) i P (u dole), bez wspólnego junction w żadnym miejscu
przecięcia. Podpis na schemacie: "S1 crossfeed: ON = przesluch -14 dB w
basie (<700 Hz), OFF = tor prosty".

**Zmiany w `headamp/check.py`.** Sekcja "CROSSFEED S1" przepisana pod
nową topologię: `same(J401.1, R401.1, R403.1, C401.1)` (gniazdo L, bez
przełącznika po tej stronie), `same(R401.2, C401.2, RV1.1, SW401.5)`
(wyjście toru prostego L + COM sekcji B), analogicznie dla P; `same(R405.2,
SW401.1)` / `same(R406.2, SW401.4)` (R405/R406 -> styk); dodane
`diff(SW401.1, SW401.2)` / `diff(SW401.4, SW401.5)` (styk != COM - test
że nie ma przypadkowego zwarcia stykiem-COM na schemacie).

## Montaż — propozycja rozmieszczenia (2026-09-08, poprawki tego samego dnia)

Propozycja fizycznego rozmieszczenia elementów w obudowie (rzut z góry,
**260×200 mm wnętrza** — zmniejszone z pierwotnych 300×250, patrz "Obudowa
zwarta" niżej, skala 1:1) — `headamp/layout/layout_top.py` (Python +
matplotlib, bez KiCada) → `headamp/ref/layout_top.svg`/`.png`. Tabela
przydziału elementów toru audio (nóżki podstawek lamp vs listwy
lutownicze) — `headamp/ref/layout_bom_montaz.md`.

Założenia (nie zmieniać bez decyzji użytkownika): montaż **powietrzny**
toru audio (listwy lutownicze + elementy dolutowane wprost do nóżek
podstawek lamp, wg zasady "stoppery/zwora przy lampie, RC katodowe i
odsprzęganie na listwach"). Lewa strefa (x 0–100 mm) = zasilanie: T301 (oś
równolegle do X) tył-lewo, L1 przed nim, IEC+F1 **w ścianie lewej, z
przodu** (patrz "Poprawki 2026-09-08, runda 2" niżej — pierwotnie planowane
w ścianie tylnej, przeniesione z powodu kolizji z T301), zarezerwowana
strefa "PCB zasilacza" 90×140 mm pod płytą. Prawa strefa (x 100–260) =
audio: OPT T1/T201 przy tylnej ścianie (oś obrócona 90° względem T301),
EL84 tuż przed swoimi OPT, ECC82 z przodu pośrodku między EL84 (≥35 mm
odstępu między lampami, ≥25 mm od transformatorów, **oraz ≥100 mm
T301↔RV1/RCA/ECC82** — wszystkie trzy reguły sprawdzone w skrypcie
automatycznie, geometria OK bez kolizji). Front (y=0), od lewej: J1+F1
(ściana lewa, x=0, y≈6–54) — SW1+NE1 (przesunięte w prawo, x=58/80) —
SW401 (crossfeed) — RV1 — SW2/SW202 — J403. Tył (y=200): J401/J402 RCA
(środek-prawo, z dala od T301).

**DECYZJA: zasilacz na PCB** (nie powietrznie; potwierdzone 2026-09-08,
zamyka wcześniejszą "otwartą decyzję"). Strefa 90×140 mm pod płytą (lewa
strefa zasilania) to **PCB zasilacza**: mostki HT, filtr CLC (bez dużych
elektrolitów, jeśli C302/C303 pójdą w "kubku" na górnej płycie — obie
opcje zostają otwarte, patrz niżej), K1 (przekaźnik rozładowania),
LD1085 + radiator, sieć ochronna wejścia (NTC/warystor/neon-rezystor),
ground breaker (jeden punkt GND↔PE, przy IEC). Uzasadnienie decyzji:
1) elementy mechaniczne wymagają solidnego mocowania, którego PCB nie
   zapewnia dobrze samo z siebie: radiator LD1085 (skręcany do chassis),
   przekaźnik K1 (masa, wibracje), potencjalnie 10000 µF (V_RAW) — to
   wszystko lepiej trzymać na płytce przykręconej do chassis, nie na
   przewodach powietrznych; 2) odstępy izolacyjne przy ~300 V DC są
   łatwiejsze do zagwarantowania i powtarzalne na projektowanej płytce
   (kontrolowane szczeliny/prześwity) niż przy ręcznym montażu
   powietrznym; 3) **blok wspólny serii** (`common/`, LD1085 + elewacja +
   K1 + ground breaker identyczne jak RIAA) — jedna płytka PCB obsługuje
   docelowo trzy urządzenia serii TERCET, więc zaprojektowana raz się
   nie marnuje.
   Elementy pozostające na chassis (górna płyta), NIE na PCB: **T301, L1,
   IEC J1+F1, SW1, NE1** (front) — mechaniczne/ciężkie lub muszą fizycznie
   przebijać obudowę (gniazda/przełączniki panelowe).
   TODO: projekt PCB zasilacza (KiCad; Konnect wymaga konfiguracji IPC dla
   narzędzi PCB — patrz CLAUDE.md).

**L1 (dławik 5–10 H, ~0,5–1 kg) — DECYZJA: zostaje na chassis (górnej
płycie), NIE na PCB.** Powód: masa i objętość dławika (rdzeń z
uzwojeniem) czynią go elementem typowo mocowanym mechanicznie do metalu
(śruba przez rdzeń/klamrę), a nie lutowanym na płytce — PCB nie udźwignie
takiego ciężaru bez dodatkowego wsparcia mechanicznego, więc prościej
zostawić go tam, gdzie mocowanie jest naturalne. L1 stoi na górnej płycie
tuż przed T301 (patrz rysunek), w tej samej strefie co PCB zasilacza
(PCB fizycznie POD nim, na osobnej warstwie — brak kolizji, to inna
płaszczyzna montażu).

**Obudowa zwarta: 260×200 mm (z 300×250).** Przeliczone na realnych
footprintach: T301 85×70, L1 55×45, OPT 55×45 ×2, podstawki noval Ø22 +
kołnierz, RV1 (galka Ø26 + korpus 40×26 od spodu). Zmiany geometrii
względem pierwszej propozycji:
- Strefa zasilania (x 0–100) bez zmian szerokości (T301 i tak potrzebuje
  ~95 mm z marginesem) — oszczędność przyszła z osi Y i strefy audio.
- EL84 (U2/U202) przesunięte bliżej środka (x=128/228, było 140/240) i
  bliżej frontu (y=90, było 150) — mniejszy odstęp od OPT (nadal ≥25 mm,
  sprawdzone: 28,5 mm po korekcie) i od siebie (100 mm, zapas nad
  wymaganymi 35 mm).
- ECC82 (U1) przesunięty na x=178 (było 190), y=45 bez zmian.
- Wysokość obudowy zmniejszona ze 250 na 200 mm — puste pole audio
  (dawne y≈60–140 z pierwszej propozycji) zamknięte przez przesunięcie
  EL84/OPT bliżej frontu.
- Wynik: 260×200 mm = 52 000 mm² vs 300×250 mm = 75 000 mm² (~31%
  mniejsza powierzchnia górnej płyty), marginesy od ścian dla elementów
  stojących swobodnie (T301/L1/OPT/lampy/strefa PCB) zachowane w
  okolicach 8–13 mm (nie ściśle wymuszone skryptem — sprawdzone wizualnie
  na renderze, patrz "Weryfikacja" niżej).

**Trasa sygnału i listwa C (poprawka).** Listwa C (crossfeed, R401–R406/
C401–C404) przesunięta **na prawo od RV1** (między RV1 a prawą ścianą,
blisko trasy z RCA) — poprzednio leżała na lewo od RV1, co oznaczało
krzyżowanie się trasy sygnału z frontem płyty. Nowa trasa: RCA (tył,
środek-prawo) → wzdłuż prawej krawędzi obudowy → listwa C → RV1 → ECC82.
Kabel ekranowany na całej tej trasie (podpisane na rysunku).

**Szyna masy (poprawka rysunku, aktualna wersja — patrz też "runda 2"
niżej).** Łamana **ortogonalna** (bez przekątnych): odcinek poziomy na
wysokości listw B (y=122) łączący wprost listwa B_L → listwa B_P, plus
pionowy odczep w x=178 do listwy A (y=122→70). Od listwy B_L dodatkowy
odcinek — korytarzem x≈101 mm (czysty prześwit między L1/T301 a T1, bez
przecinania żadnego transformatora/dławika) — do punktu ground breaker
**na PCB zasilacza, przy IEC** (aktualnie w ścianie lewej, front — patrz
"runda 2") — jedyny styk masy sygnałowej z chassis/PE, podpisane wprost
na rysunku ("masa sygnałowa ≠ chassis poza tym punktem").

**Weryfikacja (po poprawkach).** `layout_top.py` — wynik automatycznej
kontroli geometrii: **brak kolizji na górnej płycie, wszystko w
obudowie, odstępy lamp/trafo (≥35 mm między lampami, ≥25 mm lampa↔trafo)
oraz nowa reguła T301↔RV1/RCA/ECC82 (≥100 mm, liczone środek-środek)
zachowane** — najciaśniejszy margines to U2/U202↔OPT, 28,5 mm (zapas
3,5 mm nad wymogiem). `check.py` (schemat, bez zmian w tym kroku):
wszystkie asercje OK (58 sieci). ERC: **0 błędów, 0 ostrzeżeń** (bez
zmian względem stanu sprzed tej zmiany — rysunek montażowy nie dotyka
`headamp.kicad_sch`). Idempotencja `gen.py`: bez zmian (nie ruszany w tym
kroku). Render PNG obejrzany i poprawiony pod kątem kolizji etykiet
(m.in. opis strefy PCB zasilacza rozbity na krótki tytuł + osobny akapit,
żeby nie nachodził na etykietę L1; opis frontu rozbity na dwie linie,
żeby nie wychodził poza kadr; trasy masy/żarzenia/B+ poprowadzone poza
obrysami transformatorów zamiast po przekątnej przez nie).

**Poprawka R1/R201 (grid leak wejściowy).** W tabeli
`headamp/ref/layout_bom_montaz.md` R1 (470k, kanał L) i R201 (kanał P)
były błędnie przypisane do sekcji "między listwą A i B" (trasa sprzęgacza
driver→EL84). W rzeczywistości R1/R201 siedzą na węźle **siatki ECC82**
(między nóżką R2/C1 — pin 7 U1 unit A dla kanału L, pin 2 unit B dla
kanału P — a GND), elektrycznie niezwiązanym z sprzęgaczem C5/R6 po
stronie EL84. Poprawione: R1/R201 przeniesione do tabeli "na nóżkach
podstawek" (fizycznie: na listwie A przy wejściu siatki, albo wprost z
nóżki R2/C1 do szyny masy); sekcja "między A i B" zawiera już tylko
R6/R206 i C5/C205 — R7/R207 (grid stopper EL84) zostaje bez zmian na
nóżce EL84, jak poprzednio.

**Poprawki 2026-09-08, runda 2 (kolizja IEC, trasa żarzenia, szyna masy).**

1. **J1+F1 (IEC C14 + bezpiecznik) — kolizja z T301, przeniesione na
   ścianę lewą.** Gniazdo IEC z bezpiecznikiem ma korpus ~48×28 mm na
   ścianie i wchodzi ~30–35 mm w głąb obudowy (plus przewody) — w
   pierwotnej propozycji (ściana tylna, x≈42) kolidowało to z T301, który
   przy tej ścianie sięga do y=190. Skrypt dostał bryłę "głębokości" IEC
   48×35 mm włączoną do automatycznej kontroli kolizji. Rozważone warianty:
   (a) IEC na wysokości L1 (y≈65) + przesunięcie L1 w prawo — **odrzucony**:
   geometrycznie niewykonalny (L1, 55 mm szerokości, nie mieści się między
   krawędzią IEC a wymaganym 25 mm odstępem od U2 — dostępne miejsce to
   tylko 52 mm); (b) IEC z przodu ściany lewej (x=0, y≈6–54) +
   przesunięcie SW1/NE1 w prawo — **wybrany**. L1 zostaje bez zmian.
   Powód wyboru: najkrótsze i najprostsze prowadzenie przewodu sieciowego
   IEC(+F1) → SW1 → sieć ochronna (PCB) → T301, cały czas w obrębie strefy
   zasilania (x<100), bez zbliżania 230 V do frontu przy RV1 (x=140).
   Skutki uboczne: SW1 przesunięty z x=18 na x=58, NE1 z x=34 na x=80 (obie
   dalej na froncie, y=13, kolejność na panelu bez zmian: SW1→NE1→SW401→
   RV1→SW2→J403); C302/C303 (ilustracyjne elektrolity PCB zasilacza,
   pod płytą) przesunięte z y=45 na y=150 (nadal w strefie PCB, teraz pod
   T301) — poprzednia pozycja kolidowała wizualnie z etykietą nowego J1+F1.
2. **Trasa żarzenia (poprawka).** Korytarz między T301/L1 a T1 przesunięty
   z x≈98 na x≈101 (razem z odgałęzieniem szyny masy, patrz niżej — większy
   margines po przesunięciu L1... choć L1 finalnie zostało bez zmian,
   korytarz i tak przesunięty dla większego zapasu). Ważniejsza poprawka:
   odgałęzienie do U1 (ECC82, 178,45) **już nie schodzi przy RV1/wejściu**
   (dawna trasa: korytarz → y=45 → w prawo pod RV1/U1); teraz żarzenie
   idzie rzędem EL84 (y=90) od U2 do U202, a do U1 odczep **prosto w dół ze
   środka między EL84 (x=178, y=90→56)** — z dala od RV1 (x=140) i wejścia.
   Podpis na rysunku: "żarzenie DC – skręcona para, z dala od wejścia".
3. **Szyna masy — dostosowana do nowego IEC.** Odgałęzienie od listwy B_L
   do ground breakera zaktualizowane: korytarz x≈101 → y=45 → w lewo do
   x=20 → w dół do y=30 (wewnątrz nowej bryły J1+F1) — fizycznie
   najkrótsza droga do PCB zasilacza przy nowej pozycji IEC (ściana lewa,
   front), bez przecinania L1/T301/SW1.

**Weryfikacja (runda 2).** `layout_top.py`: kontrola geometrii automatyczna
— brak kolizji na górnej płycie (w tym nowa bryła głębokości J1+F1), wszystko
w obudowie, odstępy lamp/trafo i reguła T301↔RV1/RCA/ECC82 zachowane. Render
PNG obejrzany i poprawiony (etykieta szyny masy B_L→A→B_P podniesiona, żeby
nie nachodziła na opis listwy B_L; C302/C303 przesunięte, żeby nie nachodziły
na etykietę J1+F1). Zmiana nie dotyka `headamp.kicad_sch` / `gen.py` / ERC —
tylko rysunku montażowego i tego dokumentu.

### Uwagi do projektu PCB zasilacza (2026-09-08)
- T301 stoi na górnej płycie nad strefą PCB — śruby mocujące transformatora
  muszą minąć płytkę: przewidzieć wycięcia/otwory w PCB albo przesunąć
  płytkę ~30 mm w przód (poza obrys T301). Do rozstrzygnięcia przy projekcie.
- Crossfeed S1 — kontrolne liczby z niezależnej analizy węzłowej (źródło
  100 Ω, obciążenie 50 k): ON przesłuch −14 dB @100 Hz / −29 dB @1 kHz,
  strata wtrąceniowa 0,6–1,6 dB; OFF (S1 po stronie wyjścia) 0…−0,4 dB;
  stary wariant OFF (S1 na wejściu) dołek −1,6 dB w basie. `sim/crossfeed_sw.cir`
  do uruchomienia w ngspice, gdy będzie dostępny (brak na stacji Windows).

## Decyzja - tylko GND jako symbol (2026-09-08)
Na schemacie mają zostać wyłącznie symbole `power:GND` - żadnych innych
etykiet lokalnych/globalnych ani symboli `Earth_Protective`. Zmiana w
`headamp/gen.py`:
- **ELEV i V_RAW zamienione z etykiet (`label`) na realne druty.** ELEV:
  węzeł dzielnika elewacji (R304.2/R305.1/C304.1) → w dół do magistrali
  poziomej (y=330,2, ok. 25 mm poniżej R304/R305/K1) → odczep w górę do
  K1.A2 (junc) → dalej w prawo → w dół do szyny minus żarzenia (dawne
  "HEAT_B", ten sam węzeł co filament F2/pin9 lamp i R308.2/C307.2/C308.2).
  V_RAW: K1.A1 → jog w lewo (x=222,25, żeby nie przeciąć w tym samym
  punkcie magistrali ELEV) → w dół do własnej magistrali poziomej
  (y=334,0) → w prawo → w górę do węzła wyjścia mostka Schottky żarzenia
  (już połączonego z U301.VI/C305/C306). Obie magistrale krzyżują się ze
  sobą i z inną szyną GND bez punktu - to zwykłe, nieelektryczne
  skrzyżowania drutów (brak `junction`), zgodnie z konwencją KiCad.
- **K1 (przekaźnik rozładowania, z D305/R306) POZOSTAJE w bloku
  ZASILACZ B+**, NIE przeniesiony do ramki ŻARZENIE. Korytarz między
  blokiem rozładowania a blokiem żarzenia (y=330,2/334,0) jest wolny od
  korpusów komponentów na całej długości (drut nie przecina żadnej
  bryły), więc przeniesienie K1 nie dawało korzyści dla czytelności, a
  wymagałoby przełożenia całego okablowania +300V bus i obwodu
  rozładowania (D305/R306, styki 11/12/14 K1) bez potrzeby.
- **PWR_FLAG - zostały tylko 3, wszystkie sprawdzone empirycznie
  (usunięcie pojedynczo → ERC → przywrócenie, bo każde dawało
  `power_pin_not_driven`):**
  1. `pwrflag(224.79, y(113.03))` w `chan()` (tylko kanał L, `out_flag`) -
     powrót wtórny OPT do GND (jak w b7d6cc9); usunięty → 1 błąd ERC.
  2. `pwrflag(231.14, ...)` przy K1.A1 - sieć V_RAW zasilana wyłącznie
     przez katody diod mostka Schottky (piny pasywne), a `U301.VI` (LD1085,
     pin 3) to `power_in` → wymaga sterownika; usunięty → 2 błędy ERC.
  3. `pwrflag(387.35, YHM+2.54)` na końcu szyny minus żarzenia (dawne
     "HEAT_B", dziś ta sama sieć co ELEV) - sieć złożona wyłącznie z pinów
     pasywnych (filamenty, R304.2, R308.2/C307.2/C308.2, K1.A2, D305.2),
     zero `power_out`; usunięty → 1 błąd ERC.
  Sieć +300V (piny lamp/OPT/R/C - same pasywne) i sieć PE (patrz niżej) NIE
  mają żadnej flagi - potwierdzone, że nie są potrzebne (ERC 0/0 bez nich).
- **PE bez symbolu i bez PWR_FLAG.** Usunięte oba symbole
  `power:Earth_Protective` (przy J1 pin 3 i przy ground breakerze) razem z
  PWR_FLAG, który stał przy pierwszym z nich (okazał się zbędny - sieć PE
  ma tylko piny pasywne: J1.3 złączki oraz R309/D310/D311/C309 ground
  breakera). J1 pin 3 połączony drutem wprost do lewego końca szyny PE
  ground breakera (x=43,18/y=328,93+PSU_DY) - jeden ciągły przewód, bez
  odgałęzień. Tekst „PE -> własna śruba M4 na chassis” zostaje bez zmian.
  `headamp/check.py` **nie wymagał zmian** - asercje `diff(PE,GND)`,
  `diff(PE,N)`, `diff(PE,L)` i `same()` na parach pinów PE już tam były
  (operują na pinach z netlisty, nie na nazwach etykiet, więc nie zależały
  od tego czy połączenie szło drutem czy etykietą).
- **PDF w repo**: `headamp/ref/headamp.pdf` (nieignorowany -
  `git check-ignore` potwierdza, że `.gitignore` (`headamp/*.pdf`) nie
  obejmuje `headamp/ref/`) generowany po każdej zmianie schematu i
  commitowany razem z `headamp.kicad_sch` - krok dodany do workflow w
  `headamp/README.md` i `CLAUDE.md`.
- Weryfikacja: `check.py` OK (58 sieci, bez zmian w asercjach), ERC 0
  błędów / 0 ostrzeżeń, dwa uruchomienia `gen.py` dają identyczny plik
  (idempotencja uuid5 potwierdzona `diff`), PDF obejrzany - moduły
  ZASILACZ B+/ŻARZENIE czytelne, druty ELEV/V_RAW nie przecinają korpusów
  komponentów.

## gen.py - test geometrii drutów (Eeschema scala współliniowe druty)

Diagnoza (2026-09-08): plik z `gen.py` dawał w `kicad-cli sch erc` 0/0 i
poprawną netlistę, ale po otwarciu i ZAPISANIU w Eeschema (KiCad 10.0.6)
miał 7 błędów `pin_not_connected` + 3 `unconnected_wire_endpoint`, a liczba
drutów spadała z 251 do 233. Przyczyna: **Eeschema przy zapisie scala
współliniowe odcinki drutu stykające się końcami** (jeśli w punkcie
styku nie ma pinu/junction/trzeciego drutu) - jeśli generator wyemitował
dwa współliniowe odcinki, które się NA SIEBIE NAKŁADAJĄ (a nie tylko
stykają końcami), albo odcinek przechodzący PRZEZ pin/koniec innego
drutu bez junction w tym punkcie, scalanie gubi ten punkt jako
wierzchołek i połączenie znika - mimo że `kicad-cli` (parsujący plik
"na sucho", bez scalania) tego nie widzi.

**Test w `headamp/check_geom.py`** (wywoływany automatycznie z
`check.py`), niezależny od `gen.py` - parsuje bezpośrednio wyjściowy
`.kicad_sch` (piny liczone przez `symlib.pins()` + `symlib.xform()`,
tak jak `gen.py`, ale osobnym przebiegiem):
  1. brak nakładających się współliniowych odcinków (dotykanie samymi
     końcami OK),
  2. brak odcinka przechodzącego przez pin/koniec innego drutu bez
     junction w tym punkcie,
  3. brak odcinków < 1,27 mm,
  4. brak "dyndających" końców drutu (każdy koniec musi leżeć na
     pinie/junction/no_connect albo stykać się z innym drutem).
  5. **Emulacja scalania Eeschema** (`emulate_merge()`): scala
     współliniowe odcinki stykające się końcami w punkcie bez
     pinu/junction/trzeciego drutu (dokładnie jak robi to Eeschema),
     liczy połączenia na wyniku i porównuje partycję pinów z prawdziwą
     netlistą `kicad-cli sch export netlist` - **musi być identyczna**
     (piny `power:GND` i `power:PWR_FLAG` wyłączone z porównania - te
     symbole nie pojawiają się jako węzły w eksporcie kicad-cli).

Znalezione i naprawione w `gen.py` (wszystkie: prosta linia między dwoma
pinami przechodząca dokładnie przez pin/koniec leżący "po drodze" na tej
samej współrzędnej - naprawa = jog w bok/dół omijający kolizję, nigdy
prosta linia przez punkt trzeci):
  - R401.1-C401.1 i R401.2-C401.2 (tor prosty wejścia, kanał L) - linia
    R.1-C.1 szła przez pin R.2; naprawa: magistrala IN z junction +
    osobny jog dla pary OUT (analogicznie R402/C402, kanał P).
  - SW401 COM A -> magistrala outR: odcinek (185,42/39,37)-(185,42/36,83)
    nakładał się z początkiem magistrali (185,42/36,83)-(185,42/63,5) -
    naprawa: magistrala zaczyna się od razu w punkcie SW401 (39,37).
  - Węzeł elewacji (R304.2/R305.1) -> ELEV_BUS_Y: prosta linia w dół
    przechodziła przez oba piny R305 (ta sama kolumna x=210,82) - naprawa:
    jog przez wolną kolumnę x=200,66, wchodzi w magistralę ELEV_BUS_Y
    dopiero za kolumną R305 (magistrala tylko PRZECINA - nie kończy się na
    - sieć R305.2->GND, co jest bezpieczne, zwykłe krzyżowanie dwóch
    różnych sieci).
  - T301.5 (AC1 mostka żarzenia) szedł prosto w dół przez pin T301.6 (ta
    sama kolumna) - jog do wolnej kolumny x=114,3.
  - T301.6 (AC2) szedł poziomo przez pin D308.1 (przypadkowo ta sama
    współrzędna) - jog omijający D308 tuż przed dojściem do D309.1.
  - C403.1-R405.1 i C404.1-R406.1 (gałęzie krzyżowe) - linia szła przez
    pin C403.2/C404.2 (ten sam kondensator, oba piny na tym samym
    poziomie) - jog w bok omija.
Weryfikacja: `check_geom.py` OK, emulacja scalania = netlista kicad-cli
(0 różnic), `check.py` OK (58 sieci, te same partycje pinów), ERC 0/0,
dwa uruchomienia `gen.py` identyczne (idempotencja uuid5). Współdzielona
funkcja `xform()` (transformacja pinu wg rot/mirror) przeniesiona z
`gen.py` do `symlib.py` - używana teraz przez oba moduły.

### Stan WIP 2026-09-08 (wieczor)
Plik roboczy po recznych porzadkach: K1 podlaczony (A1->V_RAW, A2->ELEV),
PWR_FLAG na V_RAW i minusie zarzenia. KiCad przenumerowal kanal P (U3/U4/T2/
RV2/SW3/SW402/C7-C12/R10-R18/R407-R409/C405-C406) — refy +200 nieaktualne.
Otwarte: U3->U1 unit B, zarnik U202B->U4, jeden PWR_FLAG na GND za duzo,
RV2->RV1 B, SW402->SW401 B; potem check.py i docs do nowej numeracji.
Szczegoly i kolejnosc: CLAUDE.md, sekcja STAN WIP.

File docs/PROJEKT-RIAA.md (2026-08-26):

# Projekt: lampowy przedwzmacniacz gramofonowy RIAA (stereo) — ustalenia

Stan na: 2026-08-25. Właściciel: Wiktoryn. Dokument jest "pamięcią" projektu —
przy kontynuacji w nowej sesji podać ten plik Claude'owi.

## Kontekst systemu (docelowo trzy pudełka, w 100% analogowe)

1. **RIAA phono stage** (ten projekt) — schemat gotowy, rev E w KiCad 7.
2. **Końcówka mocy lampowa** — następna w kolejności; z potencjometrem
   głośności na wejściu (Alps RK27 log stereo), który po zbudowaniu
   przedwzmacniacza zostanie trymerem czułości. Wskaźniki wychyłowe (VU,
   podświetlane na ciepło, z Aliexpress) napędzane biernie z wyjść
   głośnikowych (mostek z diod germanowych/Schottky + trymer). Czułość
   projektować na ~0,4–0,5 V pełnej mocy.
3. **Przedwzmacniacz liniowy** — na końcu: selektor wejść, głośność, balans,
   mono, filtry rumble/scratch, barwa (Baxandall + stopień odrabiający).
Kolejność budowy wynika z tego, że Sony (obecna integra tranzystorowa) nie
ma pewnego MAIN IN — sprawdzić; jeśli ma, przedwzmacniacz może być drugi.

Obecny sprzęt: gramofon Technics (wkładka MM), tani RIAA tranzystorowy
(do porównań A/B), integra Sony. Lampowy RIAA wpinać w wejście LINIOWE
(AUX/CD), nigdy w PHONO (podwójna korekcja!).

## Układ elektryczny RIAA (rev E)

- Topologia: 2 stopnie wzmocnienia ECC83 + wtórnik katodowy ECC82,
  pasywna korekcja RIAA między stopniami (3180/318/75 µs).
  V1 = ECC83 kanał L (obie połówki), V2 = ECC83 kanał R, V3 = ECC82
  (połówka A → L, połówka B → R). Wzmocnienie ~40 dB @ 1 kHz, Zwy ~1 kΩ.
- Wejście MM: 47k ∥ 150p. (Opcja na przyszłość, NIEzdecydowana: przełącznik
  MM/MC/PIEZO — MC przez transformatory SUT 1:10 w mu-metalu, PIEZO przez
  tłumik ~20 dB + obciążenie 47k; na razie czyste MM.)
- Sieć RIAA (na kanał): szeregowo 255k (dodaje się do Zwy stopnia 1 ≈39k →
  294k), boczniki: 3n3 ∥ (33k + 9n62) do masy; 9n62 = 8n2+1n2+220p, 1% PP.
  Grid leak 1M, grid stoppery 470R/1k przy samych pinach lamp.
- Punkty pracy: stopnie ECC83: Ra 100k, Rk 1k5 ∥ 220µ, ~1 mA.
  Wtórnik ECC82: Rk 2k2 + 47k (grid leak 1M do odczepu), ~2,4 mA, Vk ~118 V.
  Wyjście przez 2µ2/400V, bleeder 470k.
- Zasilacz anodowy: 230 V sekundar → mostek UF4007 (+ snubber RC 470R+10n/1kV
  przez uzwojenie) → C9 100µ/500V → **L1 dławik 10H/100mA** (opcja budżetowa:
  R 1k 5W zamiast — wtedy większe tętnienia) → C10 100µ/500V = B+3 (~300 V
  z dławikiem, ~285 V z rezystorem).
  **B+ rozdzielone per kanał**: z B+3 dwie gałęzie 10k→47µ (B+2L/R) →
  22k→47µ (B+1L/R). Bleedery 470k/1W na każdym z 4 kondensatorów gałęzi.
  C9+C10 przewidziane jako kubek wielosekcyjny 100+100µF/500V (JJ) na płycie
  górnej; obejma z przekładką izolacyjną (masa ≠ chassis!).
- Transformator (kupiony w sklepie): EI84/42, 100 VA, prim. 230 V (bezp.
  T500mA), wtórne: 230 V/0,3 A (anodowe), 0–6,3–7 V/4 A (żarzenie z uzwojenia
  7 V; odczep 6,3 V niepodłączony), 24 V/0,1 A (rezerwa na polaryzację siatek
  w przyszłej końcówce — niepodłączone).
- Żarzenie: uzwojenie 7 V → mostek 1N5822 → 10000µ/16V (=V_RAW, ~9 V) →
  470µ → **LD1085** (LDO! LM317 ma za duży dropout przy 9 V surowego;
  240R/976R → 6,33 V) na radiatorze wciskanym w PCB (NIE do płyty górnej —
  blaszka = VOUT). 6,3 V DC / 0,9 A (3 lampy, piny 4+5 równolegle).
  Przy głębokich zapadach sieci LDO może na moment wyjść ze stabilizacji —
  niegroźne dla żarzenia. Przekaźniki K1/K2/K3: cewki 9 V (zasilane z V_RAW).
  Żarzenie podniesione do +50 V (ELEV: dzielnik 470k/100k z B+3 + 22µ) —
  przydźwięk i Vhk wtórnika. Przewody żarzenia ZAWSZE skręcona para.
- Automatyczne rozładowanie: K1 (przekaźnik 9 V na V_RAW, styki min. 250 V,
  dioda gasząca) — przy zaniku sieci styk NC łączy B+3 z R24 4k7/10W → <50 V
  w ~15 s. Wszystkie kondensatory HT rozładowują się przez łańcuch;
  bleedery 470k to niezależna, wolna (minuty) druga linia. Przy włączeniu K1
  zapina się zanim B+ wzrośnie (żarzenie wstaje szybciej). MIMO TO: przed
  pracą zawsze pomiar woltomierzem na każdej sekcji.
- Wyciszenie wyjść: K2/K3 (Relay SPDT 9 V) zwierają wyjścia L/R do masy;
  Q1 2N7000 z RC 470k/220µ (D 1N4148 do szybkiego rozładowania przy
  wyłączeniu) otwiera po ~20 s od włączenia → brak stuków i szumu rozgrzewki,
  natychmiastowy mute przy wyłączeniu.
- Sieć: IEC z bezpiecznikiem T500mA (w L, przed wyłącznikiem) → SW1
  dwubiegunowy toggle (L i N, metalowa dźwignia, 250 VAC) → NTC 10R (inrush)
  → transformator. Warystor S14K275 przez L–N za wyłącznikiem (opcja: +100n
  X2). NE1 neonówka + 220k przez uzwojenie pierwotne = kontrolka w oprawce
  "jewel" (bursztyn) na froncie, osobno od wyłącznika. Świeci = trafo pod
  napięciem.

## Masa i bezpieczeństwo (NIEnegocjowalne)

- PE z IEC → osobna śruba M4 na płycie górnej (podkładka ząbkowana, nakrętka).
- Masa sygnałowa (GND) = osobna sieć wewnątrz; z chassis łączy się w JEDNYM
  punkcie przy gniazdach wejściowych przez **ground breaker**: 10R/5W ∥ dwie
  1N5408 antyrównolegle ∥ 100n/630V. Cisza pętli masy + przy usterce diody
  zwierają do PE i bezpiecznik działa.
- Gniazda RCA izolowane od metalu. Zacisk masy gramofonu → GND (nie chassis).
- KAŻDY dotykalny/sieciowy element metalowy (płyta górna, tylna blacha,
  front) → oczko na PE. Przewody 230 V: skrętka, podwójna izolacja,
  termokurczka na terminalach, z dala od wejść.
- Napięcia do ~330 V DC — śmiertelne. Praca dopiero po pomiarze <50 V.

## Obudowa (seria trzech urządzeń w tym samym stylu)

- Format: szerokość/głębokość jak standardowy sprzęt audio (~430×300).
  Wymiary finalne TBD — od nich DXF.
- Boki + spód: drewno (robi znajomy). Spód z tulejkami gwintowanymi (M3/M4)
  pod PCB zasilacza, pola otworów wentylacyjnych pod lampami i pod strefą
  zasilacza, wysokie nóżki; pod PCB zasilacza cienka blaszka/mata niepalna.
- Góra: stal nierdzewna lustrzana ("super mirror" No.8, 1,5 mm, cięta laserem
  z folią). Na wierzchu: 3 lampy (gniazda od spodu, szczelina wokół bańki =
  kominek), kubki elektrolitów HT, transformator (dzwon lub kubek ekranujący;
  transformator w rogu, ≥25 cm od lamp wejściowych). Góra = chassis
  elektryczne.
- Tył: blacha malowana proszkowo (2 mm alu) — RCA (izolowane), IEC+bezpiecznik,
  zacisk masy; szczeliny wentylacyjne (wylot) + siatka od środka.
- Przód: szczotkowana nierdzewka, wpuszczona/licowana w drewno (frez),
  mocowanie na wklejanych szpilkach M3 od tyłu (zero widocznych śrub).
  Na RIAA tylko: toggle + jewel neonówki. Wspólny wzór dla trzech urządzeń
  (ten sam prostokąt, promień naroży, czcionka — Futura/DIN, wersaliki).
- Oznaczenia frontu: znakowanie laserem fiber (annealing — czarne napisy na
  szczotce). Nie kwas, nie sitodruk.
- Wentylacja: wlot dołem, wylot tyłem + kominki lamp; ~15 W strat, bez
  wiatraków. Radiator LD1085 przy tylnych szczelinach,
  elektrolity po chłodnej stronie; 3–4 cm luzu nad PCB.

## Montaż

- Tor audio: turret board (tulejki 2 mm w laminacie), zawieszony na
  przedłużonych śrubach gniazd lamp (tulejki dystansowe 15–20 mm).
  Grid stoppery lutowane wprost na pinach gniazd. Kanały L/R lustrzanie.
  Gniazda: ceramiczne noval z kołnierzem, śruby imbusowe M3 nierdzewne.
- Zasilacz + automatyka (K1/K2/K3, LD1085, mostki, NTC): jedno PCB na spodzie,
  prawy tylny róg (przy IEC i trafo, daleko od wejść). Odstępy ścieżek ≥2,5 mm
  przy 300 V. PCB zaprojektuje Claude z tego samego projektu KiCad.
- Masa: szyna/gwiazda na turret boardzie, punkt styku z chassis przez ground
  breaker przy wejściach. Kubki: sekcje minusów w jednym punkcie.
- Sieć 230 V: bez PCB, na konektorach, w rogu zasilacza.

## Pliki projektu

- `riaa_preamp.kicad_sch` — schemat (KiCad 7, symbole osadzone, otwiera się
  bez bibliotek). Generowany skryptem `gen.py` (+ `symlib.py`, `check.py` —
  weryfikacja netlisty). Rev E = finalna wersja przed budową.
- `riaa_preamp.pdf` — render do czytania/druku.
- TBD po wymiarach: DXF płyt (góra lustrzana, tył, front ×3), layout PCB
  zasilacza, rysunek rozmieszczenia, BOM zakupowy.

## Oświetlenie lamp (opcja, oba warianty)

Miniaturowe żarówki 6,3 V/0,1 A (T1¼, E5/E10) pod podstawkami — światło przez
otwór po środkowym styku "shield" (nieużywany w noval; usunąć lub podstawka
z pustą tulejką) + przez szczelinę wokół bańki. Jasność: szeregowy REGULOWANY
rezystor drutowy 0–22R/10 W (z obejmą), strojony od środka. Wyłącznik SPST
(OŚWIETLENIE) na tylnej ściance. Przewód: skrętka w ekranie, ekran do GND
tylko od strony zasilacza. Zasilanie: rev E — wolny odczep 6,3 V AC;
rev P — uzwojenie 6,3 V EZ81 pod warunkiem dowiązania go do GND zamiast do
katody (Vhk = −300 V, limit EZ81 500 V) — inaczej oświetlenie na +300 V.
Montaż podstawek: otwór w płycie 26–28 mm, podstawka pod płytą na tulejkach
5–8 mm → pierścieniowa szczelina = kominek wentylacyjny + poświata
(podstawka przykręcona na styk do płyty zamyka otwór — tak NIE robić).

## TODO: filtrowanie zakłóceń (do ogarnięcia przed/na etapie budowy)

Temat otwarty — zakłócenia z dwóch kierunków, oba do rozwiązania:

**Z sieci 230 V (przewodzone):** obecnie mamy warystor + NTC + snubber RC na
uzwojeniu HT. Do dodania pełny filtr przeciwzakłóceniowy EMI na wejściu:
najprościej gniazdo IEC ze zintegrowanym filtrem (np. Schaffner FN9222,
Schurter 5110 — dławik wspólny + kondensatory X2/Y2 w jednej puszce,
prąd 1–2 A wystarczy) albo osobny moduł filtra za wyłącznikiem.
Uwaga na kondensatory Y (L→PE, N→PE): świetnie tłumią zakłócenia
wspólne, ale wpuszczają mały prąd upływu do PE — przy naszym ground
breakerze to nieszkodliwe (upływ idzie do chassis/PE, nie do masy
sygnałowej), lecz filtr MUSI być certyfikowany (X2/Y2), nie składany
z przypadkowych kondensatorów. Rozważyć też: osobne odkłócenie od strony
DC (perełki ferrytowe na wyjściach zasilacza do B+ i żarzenia).

**Z "powietrza" (RF/pola):** wejścia MM to najczulszy punkt — 5 mV przy
47 kΩ łapie radio, ładowarki, LED-y i telefon na obudowie. Warstwy obrony:
grid stoppery już są (470R/1k przy pinach); do rozważenia dodatkowo małe
perełki ferrytowe lub RC (np. 1k + 100p) bezpośrednio na gniazdach RCA
wejściowych; przewody wejściowe wewnątrz obudowy ekranowane (ekran do GND
tylko od strony gniazd); metalowa górna płyta + tylna blacha robią klatkę —
sprawdzić po złożeniu, czy drewniane boki nie wpuszczają RF (jeśli tak:
samoprzylepna folia miedziana/aluminiowa na wewnętrznych stronach desek,
połączona z PE w jednym punkcie); kabel od gramofonu możliwie krótki,
zacisk masy ramienia podłączony. Test praktyczny po budowie: telefon
z włączonym transferem danych położony na obudowie + max głośność —
cisza oznacza zdany egzamin.

Decyzje do podjęcia przy budowie: filtr IEC zintegrowany czy osobny moduł;
czy foliować drewno; czy RC na wejściach od razu, czy dopiero jeśli
słychać RF (wersja purystyczna: dodawać tylko to, co potrzebne).

## Wariant purystyczny (zero półprzewodników) — **DECYZJA: TO BUDUJEMY**

**Decyzja (2026-08-26): wersja purystyczna (rev P) jest wersją docelową
do budowy.** Rev E zostaje w repo jako udokumentowana alternatywa
(krzem usługowo w zasilaczu) — nie kasować.

### Transformatory: DWA identyczne EI84 100VA (decyzja)

Nie znaleziono trafo 2×230 V z odczepem — zamiast tego **dwa identyczne
trafa EI84/42 100VA** (to samo, które już kupione do rev E: 230 V 0,3 A /
24 V 0,1 A / 0-6,3-7 V 4 A):

- **Pierwotne obu — równolegle** do sieci (za F1, SW1, R34 — wspólne).
- **Wtórne 230 V — szeregowo**; punkt połączenia = odczep środkowy → GND.
  Końce skrajne → anody EZ81. ⚠ **FAZOWANIE przy pierwszym uruchomieniu**
  (przez żarówkę szeregową): połączyć po jednym końcu wtórnych, zmierzyć
  między pozostałymi — **~460 V AC = dobrze**, ~0 V = odwrócić końcówki
  jednego uzwojenia. Między anodami ~650 V szczytowo — przewody o dobrej
  izolacji; EZ81 w limicie (2×350 V RMS).
- **6,3 V trafa nr 1** → żarzenie EZ81, dowiązane klasycznie do katody
  (znika problem +300 V na okablowaniu oświetlenia — patrz niżej).
- **6,3 V trafa nr 2 — wolne** → zasila OŚWIETLENIE lamp (opcja):
  izolowane, na potencjale masy, zero kompromisów.
- Uzwojenia 24 V i odczepy 7 V — niewykorzystane.
- **Bezpiecznik F1: T800mA–1A zwłoczny** (dwa rdzenie EI = podwójny prąd
  rozruchu); R34 22R zostaje, wspólny.
- Obciążenie B+ ~25–30 mA przy uzwojeniach 0,3 A → trafa prawie bez
  obciążenia, B+ wyjdzie raczej ~340 V niż 300 V — **droppery dostroić
  przy uruchomieniu** (pomiar, ew. zwiększyć R18/R19).
- Montaż: oba trafa jak najdalej od wejść i V1, osie uzwojeń obrócone
  o 90° względem siebie (minimalne sprzężenie brumu). Waga: ~4 kg samych
  trafo — dno obudowy musi to unieść.
- **Żarzenie z baterii prowadzić „gwiazdą"**: osobna skręcona para od
  baterii do każdej lampy (nie łańcuszkiem) — prąd jednej lampy nie płynie
  przewodem drugiej.

**TODO (etap KiCad przez MCP/Konnect):** przerysować schemat rev P
pod dwa transformatory (T1+T2, jak wyżej; notka o fazowaniu na schemacie,
oświetlenie z 6,3 V T2) + zaktualizować BOM. Schemat w repo pokazuje
jeszcze jedno trafo 2×230 V CT.

Tor audio już jest w 100% lampowo-bierny; zmiany dotyczą wyłącznie zasilacza.

**Prostownik anodowy:** lampa EZ81/EZ80 (lub GZ34). Wymaga INNEGO trafo:
uzwojenie anodowe z odczepem środkowym (2×230 V) + uzwojenie żarzenia
prostownika. Bonus: naturalny miękki start (katoda grzeje się ~15 s,
B+ wstaje po lampach audio) — znika potrzeba układu wyciszania. Filtr LC
(dławik obowiązkowy). Odczep środkowy robimy z DWÓCH traf EI84 — patrz
podsekcja „Transformatory" wyżej.

**Żarzenie — prostowanie lampą NIE działa (rachunek):** lampy prostownicze
to wysokie V / małe I; przy 6,3 V/0,9 A spadek ~20 V na bańce oznacza
uzwojenie ~30 V i ~50 W strat (plus żarzenie samych prostowników), żeby
dostarczyć 5,7 W. Nikt tego nigdy nie robił. Dwie realne opcje:
1. **AC + humdinger**: skręcona para, potencjometr 100R między końcami
   żarzenia (suwak do masy/elewacji, strojenie na minimum brumu), elewacja
   +50 V zostaje. Klasyka (Marantz 7); ryzyko resztkowego przydźwięku.
2. **Bateria (era-correct "bateria A")**: AGM/żel 6 V / 10–12 Ah w obudowie.
   DC idealnie czyste (zero tętnień). 6–7 h grania przy rozładowaniu do 50%.
   Rygory: TYLKO AGM/żel (szczelny), bezpiecznik BEZPOŚREDNIO przy zacisku
   (ołów oddaje setki A w zwarcie), obejma do dna (masa sprzężona sztywno =
   + stabilność, − mikrofonowanie), z dala od ciepła lamp.
   Ładowanie: ładowarka ZEWNĘTRZNA (krzem poza obudową — nie jest częścią
   urządzenia), etapowa z trybem float 6,75–6,9 V — akumulator może wisieć
   na buforze bez ograniczeń (jak w UPS). Gniazdo ładowania z tyłu.
   Przełącznik dwupozycyjny PRACA/ŁADOWANIE na froncie (2-biegunowy, 6 V DC,
   bez trybu trzeciego — float załatwia sprawę).
   **Strażnik baterii**: przekaźnik z cewką 230 V AC za wyłącznikiem
   sieciowym, styk szeregowo bateria→żarzenie — sieć wyłączona = bateria
   odcięta (nie da się jej zapomnieć w pozycji PRACA). Drugi styk (NC) tego
   samego przekaźnika = rozładowanie B+ (funkcja K1 bez diody gaszącej;
   dla cewki AC snubber RC zamiast diody).
   **Woltomierz na froncie**: miernik wychyłowy + rezystor-mnożnik, wpięty
   ZA przekaźnikiem (wskazuje tylko podczas grania — brak stałego poboru);
   zielona strefa 6,0–6,4 V jako "wskaźnik paliwa".

**Reszta zamian:** K2/K3+Q1 (muting) → zbędne przy wolnym starcie EZ81
(ew. przekaźnik termiczny Amperite, NOS). NTC → rezystor drutowy 22–47R
w pierwotnym albo nic. Warystor → wypada (ceramika półprzewodnikowa).
Ground breaker: bez diod — 10R∥100n (kompromis) albo masa na sztywno do
chassis przy wejściach (jak vintage). Neonówka, snubbery RC, bleedery,
dławiki — zostają (czysty old-tech).

**Rekomendacja (historyczna, NIEAKTUALNA):** pierwotnie rekomendowane było
rev E; decyzją z 2026-08-26 budujemy rev P (patrz nagłówek sekcji).
Kupione trafo EI84 zostaje wykorzystane — jako jedno z DWÓCH (patrz wyżej).

## Pomysły podpatrzone w innych konstrukcjach (RS Tube_RIAA_6_5)

Przejrzany zewnętrzny schemat (Eagle, 4 stopnie/kanał, zasilacz na
IRF840+LM317 — zasilacza NIE kopiujemy). Dwa patenty warte zapisania:

### 1. Wybierana pojemność wejściowa MM (zamiast stałego C1 150p)

W RS: blok kondensatorów 47/100/150/330 pF załączanych przełącznikiem DIP
równolegle do wejścia. Sens: wkładka MM + pojemność kabla + pojemność
wejściowa tworzą rezonans z indukcyjnością wkładki — producenci podają
zalecane obciążenie (typowo 150–400 pF ŁĄCZNIE z kablem). Regulacja
pozwala dostroić górę pasma pod konkretną wkładkę i kabel.

**Adaptacja do TERCET (opcja, do decyzji przy budowie):**
- NIE DIP-switch (słaby kontakt, nie na panel) — zamiast tego **przełącznik
  obrotowy 1×4 lub 2×6 (wersja stereo: 2-sekcyjny na wspólnej osi)**,
  lutowany bezpośrednio: kondensatory wprost na łukowych stykach
  przełącznika, wspólny koniec na pierścień masy — zero dodatkowego
  okablowania, minimalna pojemność montażowa.
- Wartości propozycja: 47p / 100p / 150p / 220p (mika lub C0G, 2%);
  pozycje można opisać na panelu tylnym przy RCA.
- Alternatywa tania: pozostawić stałe 150p (obecny C1), a przełącznik
  dodać dopiero, gdy zmiana wkładki tego zażąda. Montaż przy samych
  gniazdach RCA, krótkie drogi.

### 2. Nieodblokowane katody (degeneracja katodowa)

W RS wszystkie 4 stopnie mają Rk=2k2 **bez kondensatora bocznikującego** —
lokalne sprzężenie zwrotne prądowe. Zapisane jako technika do świadomego
użycia (opis mechanizmu poniżej); w TERCET rev E/P zostają katody
zablokowane (1k5 + 220µ), bo przy 2 stopniach + CF potrzebujemy pełnego
wzmocnienia ~40 dB — degeneracja wymusiłaby dodatkowy stopień (jak w RS: 4).

**Mechanizm:** bez kondensatora prąd sygnałowy płynący przez Rk wytwarza
na katodzie napięcie zgodne w fazie z siatką → skuteczne Ugk maleje →
wzmocnienie spada z A = µ·Ra/(rp+Ra) do A = µ·Ra/(rp+Ra+(µ+1)·Rk).

**Zalety:** lepsza liniowość (mniej harmonicznych, degeneracja linearyzuje
charakterystykę), mniejsza wrażliwość na rozrzut egzemplarzy lampy
(wzmocnienie zależy bardziej od Rk niż od µ i rp — łatwiej sparować
kanały), brak elektrolitu w torze sygnału (elektrolity katodowe to
najczęściej wymieniany "podejrzany" element brzmieniowy), lepsze
zachowanie przy przesterowaniu.

**Koszty:** dużo mniejsze wzmocnienie na stopień (ECC83, Ra=100k, Rk=2k2:
~57× → ~19×), wyższa impedancja wyjściowa stopnia (rp rośnie o (µ+1)·Rk),
minimalnie wyższy szum odniesiony do wejścia (mniej wzmocnienia w pierwszym
stopniu = szum kolejnych stopni waży więcej). Dlatego w RIAA pierwszy
stopień zwykle blokuje się zawsze.

**Gdzie ma sens u nas:** ew. częściowa degeneracja w DRUGIM stopniu
(katoda dzielona: część Rk zablokowana, część nie) — do rozważenia przy
strojeniu; oraz w przyszłej końcówce mocy / przedwzmacniaczu liniowym,
gdzie zapasu wzmocnienia jest dużo.

## Otwarte decyzje

- Przełącznik wkładek MM/MC/PIEZO (SUT + tłumik) — do decyzji; na razie MM.
- Dławik L1 vs rezystor 1k 5W — budżet.
- Rev E: własny symbol trafo EI84, zasilacz przerysowany (czytelny układ).
- ~~Wariant purystyczny~~ **ZDECYDOWANE (2026-08-26): budujemy rev P**; drugie trafo EI84 do kupienia.
- TODO: przerysowanie schematu rev P pod dwa trafa + BOM — etap KiCad przez MCP (Konnect).
- Wymiary obudowy — po rozmowie ze stolarzem.
- Czy Sony ma PRE OUT/MAIN IN → kolejność budowy pudełka 2 i 3.

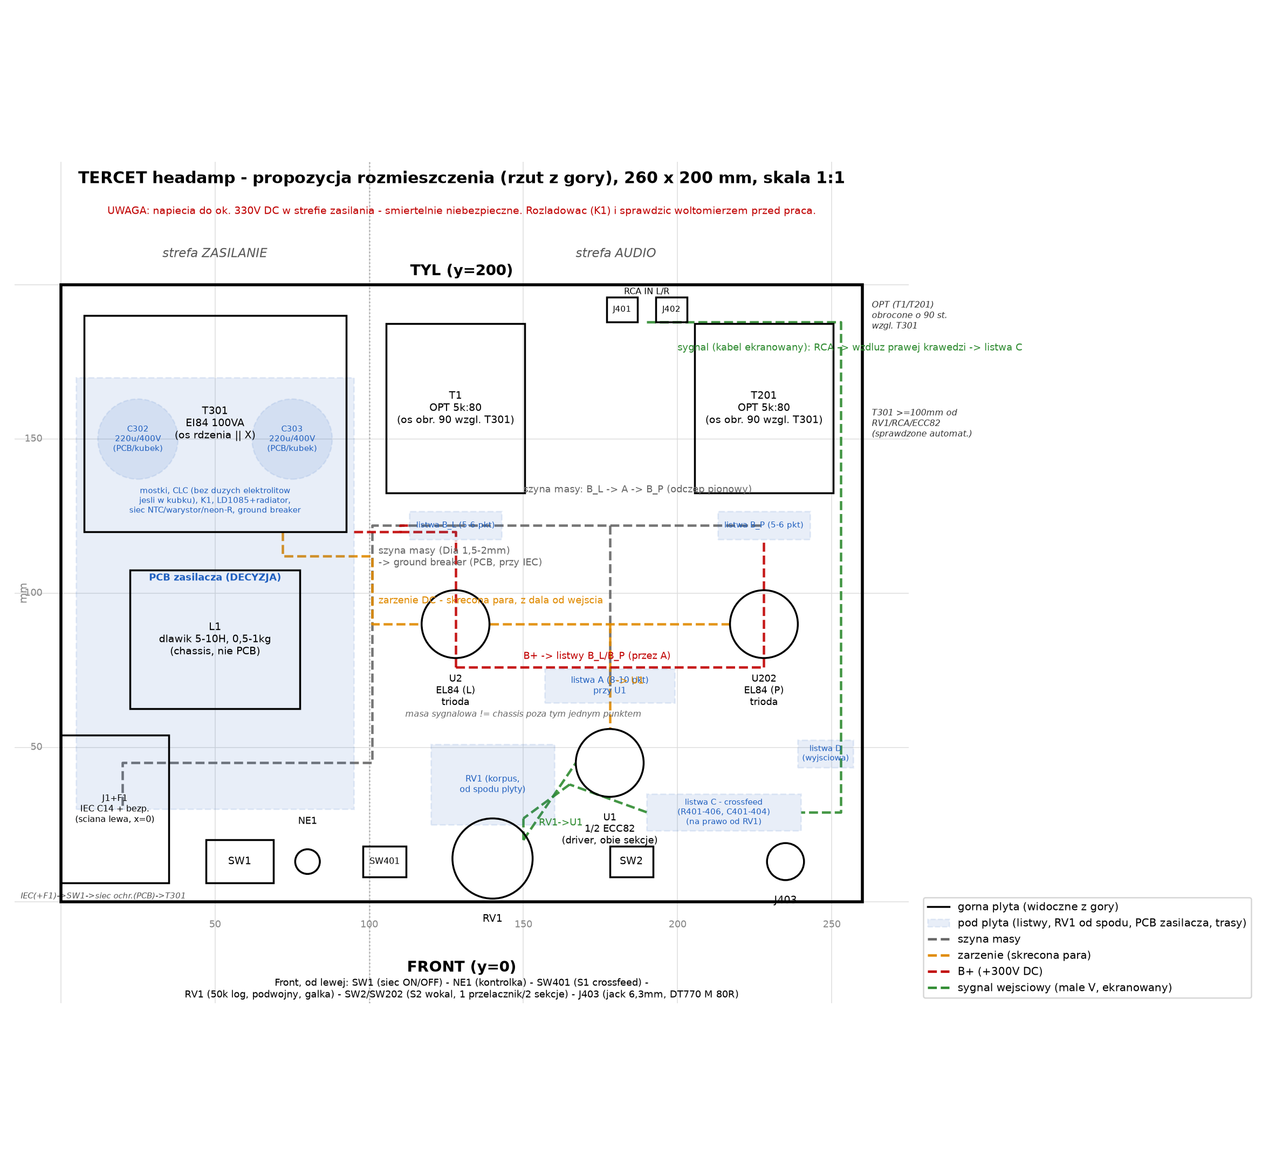
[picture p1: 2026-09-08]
headamp/ref/layout_top.png

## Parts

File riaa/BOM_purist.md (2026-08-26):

# TERCET — RIAA, wariant purystyczny (rev P) — BOM

Lista elementów wariantu **zero półprzewodników**.
Źródło: `riaa_preamp_purist.kicad_sch`, stan na 2026-08-26.

## Lampy

| Ilość | Element | Ref | Uwagi |
|---|---|---|---|
| 2 | ECC83 / 12AX7 | V1, V2 | tor audio, po jednej na kanał; egzemplarze o niskim szumie i mikrofonowaniu (selekcja „phono") |
| 1 | ECC82 / 12AU7 | V3 | wtórniki katodowe (połówka A → L, B → R) |
| 1 | EZ81 / 6CA4 | V4 | prostownik anodowy; JJ produkuje nowe |
| 4 | gniazdo noval B9A | — | ceramiczne z kołnierzem, montaż od spodu chassis, śruby M3 imbus nierdzewne |

## Transformator i dławik

| Ilość | Element | Ref | Uwagi |
|---|---|---|---|
| 1 | transformator sieciowy „lampowy" | T1 | prim. 230 V; wtórne: **2×230 V / min. 0,15 A (z odczepem środkowym!)** + 6,3 V / 1 A (żarzenie EZ81). ⚠ Kupione trafo EI84 100VA **nie pasuje** (brak odczepu) — dotyczy tylko rev E |
| 1 | dławik 10 H / 100 mA | L1 | DCR ≤ 200 Ω; filtr LC w tym wariancie **obowiązkowy** |

## Rezystory — tor audio

Metalizowane 0,6 W, o ile nie zaznaczono inaczej.

| Ilość | Wartość | Tol. | Moc | Ref | Funkcja |
|---|---|---|---|---|---|
| 2 | 47k | 1% | 0,6 W | R1, R101 | obciążenie wejścia MM |
| 2 | 470R | 5% | 0,6 W | R2, R102 | grid stopper wejściowy (lutować wprost na pinie gniazda) |
| 4 | 100k | 1% | **1 W** | R3, R9, R103, R109 | anodowe (1 W dla zapasu napięciowego) |
| 4 | 1k5 | 1% | 0,6 W | R4, R10, R104, R110 | katodowe stopni wzmacniających |
| 2 | 255k | **1%** | 0,6 W | R5, R105 | szeregowy RIAA (E96; alternatywnie 249k + 6k2) |
| 2 | 33k | **1%** | 0,6 W | R6, R106 | RIAA (bocznik szeregowy) |
| 4 | 1M | 5% | 0,6 W | R7, R11, R107, R111 | grid leak |
| 4 | 1k | 5% | 0,6 W | R8, R12, R108, R112 | grid stopper (na pinach gniazd) |
| 2 | 2k2 | 1% | 0,6 W | R13, R113 | katodowe wtórników (bias tap) |
| 2 | 47k | 1% | **1 W** | R14, R114 | katodowe wtórników (obciążenie) |
| 2 | 470k | 5% | 0,6 W | R15, R115 | upływowe wyjścia |

## Rezystory — zasilacz i pomocnicze

| Ilość | Wartość | Tol. | Moc | Ref | Funkcja |
|---|---|---|---|---|---|
| 2 | 10k | 5% | 1 W | R18, R118 | dropper B+3→B+2 (po jednym na kanał) |
| 2 | 22k | 5% | 1 W | R19, R119 | dropper B+2→B+1 |
| 4 | 470k | 5% | 1 W | R26, R27, R126, R127 | bleedery (wolne rozładowanie) |
| 1 | 470k | 5% | 1 W | R22 | dzielnik elewacji żarzenia (+50 V) |
| 1 | 100k | 5% | 0,6 W | R23 | dzielnik elewacji |
| 1 | 4k7 | 5% | 10 W drutowy | R24 | rozładowanie B+ (styk NC K1) |
| 1 | 10R | 5% | 5 W drutowy | R25 | ground breaker |
| 1 | 22R | 5% | 5 W drutowy | R34 | ogranicznik rozruchu w pierwotnym |
| 1 | 220k | 5% | 0,6 W | R32 | szeregowy neonówki |
| 1 | 100R | 5% | 0,6 W | R33 | snubber cewki K1 |
| 1 | wg miernika | 1% | 0,6 W | R30 | mnożnik woltomierza M1 (pełna skala ~8 V) |

## Kondensatory — tor audio

| Ilość | Wartość | Tol. | Typ | Ref | Funkcja |
|---|---|---|---|---|---|
| 2 | 150p | 2% | mika / C0G | C1, C101 | obciążenie wkładki MM |
| 4 | 220µ / 25 V | ±20% | elektrolit | C2, C6, C102, C106 | bocznikowanie katod |
| 4 | 100n / 630 V | 5% | polipropylen | C3, C7, C103, C107 | sprzęgające |
| 2 | 3n3 | **1%** | polipropylen | C4, C104 | RIAA (1% obowiązkowo) |
| 2 | 9n62 | **1%** | polipropylen | C5, C105 | RIAA; złożyć: 8n2 + 1n2 + 220p równolegle (wszystkie 1%) |
| 2 | 2µ2 / 400 V | 5% | polipropylen | C8, C108 | wyjściowe |

## Kondensatory — zasilacz

| Ilość | Wartość | Tol. | Typ | Ref | Funkcja |
|---|---|---|---|---|---|
| 1 | 47µ / 500 V | ±20% | elektrolit | C9 | **pierwszy po EZ81 — max 50 µF, limit lampy! Nie zwiększać** |
| 1 | 100µ / 500 V | ±20% | elektrolit | C10 | za dławikiem (B+3) |
| 4 | 47µ / 400 V | ±20% | elektrolit | C12, C13, C112, C113 | filtry B+ per kanał |
| 1 | 22µ / 100 V | ±20% | elektrolit | C17 | elewacja żarzenia |
| 1 | 100n / 630 V | 10% | polipropylen | C18 | ground breaker |
| 1 | 100n / 630 V | 10% | polipropylen | C21 | snubber cewki K1 |

> C9+C10 opcjonalnie jako kubek wielosekcyjny 50+100 µF / 500 V na płycie
> górnej — obejma z przekładką izolacyjną (masa ≠ chassis).

## Żarzenie z baterii

| Ilość | Element | Ref | Uwagi |
|---|---|---|---|
| 1 | akumulator AGM/żel 6 V / 10–12 Ah | BT1 | typ „UPS/alarm"; **tylko szczelny AGM lub żel** |
| 1 | bezpiecznik 2 A zwłoczny + oprawka | F2 | montaż **bezpośrednio przy zacisku baterii** |
| 1 | obejma / rama baterii | — | sztywne skręcenie z dnem obudowy |
| 1 | ładowarka buforowa 6 V AGM | — | **zewnętrzna**, etapowa z trybem float 6,75–6,9 V (nie wchodzi w BOM urządzenia) |

## Automatyka / sterowanie

| Ilość | Element | Ref | Uwagi |
|---|---|---|---|
| 1 | przekaźnik DPDT, cewka 230 V AC | K1 | np. Finder 40.52, Relpol R2; styki min. 250 V ze zdolnością łączenia DC; gniazdo + zatrzask |
| 1 | wyłącznik dźwigniowy sieciowy | SW1 | DPST/DPDT 250 V AC 3 A, metalowa dźwignia (front) |
| 1 | przełącznik PRACA/ŁADOWANIE | SW2 | DPDT 6 A, dźwigniowy (front); przełącza baterię: lampy / gniazdo J6 |
| 1 | neonówka NE-2 + oprawka „jewel" | NE1 | bursztynowa (front) |
| 1 | woltomierz wychyłowy | M1 | zakres ~8 V DC (lub 100 µA + R30); zaznaczyć strefę 6,0–6,4 V (front) |

## Złącza / mechanika / sieć

| Ilość | Element | Ref | Uwagi |
|---|---|---|---|
| 4 | gniazdo RCA | J1–J4 | **izolowane od chassis** (podkładki) |
| 1 | gniazdo IEC C14 z szufladką bezpiecznika | J5 | tylna ścianka |
| 1 | bezpiecznik T500mA (5×20, zwłoczny) | F1 | w L, przed SW1 |
| 1 | złącze zaciskowe 2-pin | J6 | ładowanie 6 V (tył); biegunowość opisać na panelu |
| 1 | zacisk masy gramofonu | — | śruba radełkowana; masa gramofonu → GND, nie chassis |
| — | przewód żarzenia | — | skręcona para, min. 1 mm² (0,9 A) |
| — | turret board, tulejki, dystanse | — | wg ustaleń montażowych (`docs/PROJEKT-RIAA.md`) |

## Oświetlenie lamp (opcja dekoracyjna)

| Ilość | Element | Ref | Uwagi |
|---|---|---|---|
| 3 | żarówka miniaturowa 6,3 V / 0,1 A | LA1–LA3 | T1¼ / trzonek E5 lub E10; pod podstawkami lamp audio (przez otwór po środkowym styku „shield") |
| 3 | oprawka E5/E10 | — | montaż pod podstawką |
| 1 | rezystor drutowy **regulowany** 0–22 Ω / 10 W | R35 | z obejmą/suwakiem; szeregowo — jasność ustawiana **od środka**, raz na stałe |
| 1 | wyłącznik SPST | SW3 | tylna ścianka: OŚWIETLENIE ON/OFF |
| — | przewód: skrętka w ekranie | — | ekran do GND **tylko z jednej strony** (od zasilacza); trasa po kątach, z dala od wejść |

**Zasilanie:** rev E — odczep 6,3 V AC trafo (izolowany od DC żarzenia).
Rev P — uzwojenie 6,3 V EZ81, **warunek:** koniec uzwojenia dowiązać do GND
zamiast do katody (Vhk EZ81 = −300 V, w limicie 500 V) — inaczej okablowanie
oświetlenia siedzi na +300 V!

**Montaż pod kominek + poświatę:** otwór w płycie 26–28 mm (większy niż
bańka ~22 mm), podstawka **pod** płytą na tulejkach dystansowych 5–8 mm →
pierścieniowa szczelina wokół szkła przepuszcza powietrze i światło;
pierścień ozdobny maskuje krawędź otworu. Środkowy styk „shield" podstawki
(nieużywany przez lampy noval) usunąć lub wybrać podstawkę z pustą tulejką.

## Uwagi końcowe

1. **Ground breaker bez diod** (10R ∥ 100n) — kompromis wariantu purystycznego;
   alternatywa vintage: masa na sztywno do chassis przy gniazdach wejściowych.
2. Napięcia robocze kondensatorów jak w tabelach (400/500/630 V) — nie schodzić niżej.
3. **Tolerancje:** 1% tam, gdzie wartość ustala korekcję lub punkt pracy
   (RIAA — obowiązkowo; katody/anody — dla powtarzalności kanałów);
   5% dla grid stopperów, upływowych, dropperów i bleederów; elektrolity ±20%
   (wartości filtrów mają duży zapas). Elementy RIAA kupić po kilka sztuk
   i sparować miernikiem między kanałami.
4. ⚠ **Napięcia do ~330 V DC.** Przed pracą odczekać na rozładowanie (K1/R24 +
   bleedery) i sprawdzić woltomierzem każdą sekcję (<50 V).

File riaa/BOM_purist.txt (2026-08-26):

================================================================================
 TERCET — przedwzmacniacz gramofonowy RIAA, WARIANT PURYSTYCZNY (rev P)
 BOM — lista elementów (zero półprzewodników)
 Źródło: riaa_preamp_purist.kicad_sch, 2026-08-26
================================================================================

LAMPY
--------------------------------------------------------------------------------
 2 szt   ECC83 / 12AX7        V1, V2        tor audio, po jednej na kanał;
                                            wybrać egzemplarze o niskim szumie
                                            i mikrofonowaniu (selekcja "phono")
 1 szt   ECC82 / 12AU7        V3            wtórniki katodowe (A→L, B→R)
 1 szt   EZ81 / 6CA4          V4            prostownik anodowy; JJ produkuje nowe
 4 szt   gniazdo noval B9A    —             ceramiczne, z kołnierzem, montaż od
                                            spodu chassis, śruby M3 imbus nierdz.

TRANSFORMATOR I DŁAWIK
--------------------------------------------------------------------------------
 1 szt   transformator        T1            prim. 230 V; wtórne: 2×230 V / min.
         sieciowy "lampowy"                 0,15 A (Z ODCZEPEM ŚRODKOWYM!) oraz
                                            6,3 V / 1 A (żarzenie EZ81).
                                            UWAGA: kupione trafo EI84 100VA
                                            NIE pasuje (brak odczepu) — dotyczy
                                            tylko wariantu rev E.
 1 szt   dławik 10 H / 100 mA L1            DCR ≤ 200 R; filtr LC jest w tym
                                            wariancie OBOWIĄZKOWY

REZYSTORY — tor audio (metalizowane 0,6 W, o ile nie zaznaczono; RIAA: 1%)
--------------------------------------------------------------------------------
 2 szt   47k   1%             R1, R101      obciążenie wejścia MM
 2 szt   470R  5%             R2, R102      grid stopper wejściowy (lutować
                                            wprost na pinie gniazda lampy)
 4 szt   100k  1%             R3, R9,       anodowe; 1 W dla zapasu napięciowego
                              R103, R109
 4 szt   1k5   1%             R4, R10,      katodowe stopni wzmacniających
                              R104, R110
 2 szt   255k  1%             R5, R105      szeregowy RIAA (E96; alternatywnie
                                            249k + 6k2)
 2 szt   33k   1%             R6, R106      RIAA (bocznik szeregowy)
 4 szt   1M    5%             R7, R11,      grid leak
                              R107, R111
 4 szt   1k    5%             R8, R12,      grid stopper (na pinach gniazd)
                              R108, R112
 2 szt   2k2   1%             R13, R113     katodowe wtórników (bias tap)
 2 szt   47k   1% 1 W         R14, R114     katodowe wtórników (obciążenie)
 2 szt   470k  5%             R15, R115     upływowe wyjścia

REZYSTORY — zasilacz i pomocnicze
--------------------------------------------------------------------------------
 2 szt   10k  5% 1 W          R18, R118     dropper B+3→B+2 (po jednym na kanał)
 2 szt   22k  5% 1 W          R19, R119     dropper B+2→B+1
 4 szt   470k 5% 1 W          R26, R27,     bleedery (wolne rozładowanie)
                              R126, R127
 1 szt   470k 5% (1 W zapas)  R22           dzielnik elewacji żarzenia (+50 V)
 1 szt   100k 5%              R23           dzielnik elewacji
 1 szt   4k7  5% 10 W drut.   R24           rozładowanie B+ (styk NC K1)
 1 szt   10R  5% 5 W drut.    R25           ground breaker
 1 szt   22R  5% 5 W drut.    R34           ogranicznik rozruchu w pierwotnym
 1 szt   220k 5% (0,6 W)      R32           szeregowy neonówki
 1 szt   100R 5%              R33           snubber cewki K1
 1 szt   wg miernika, 1%      R30           mnożnik woltomierza M1 (dobrać:
                                            pełna skala ~8 V)

KONDENSATORY — tor audio
--------------------------------------------------------------------------------
 2 szt   150p  2% mika/C0G    C1, C101      obciążenie wkładki MM
 4 szt   220u/25V el. ±20%    C2, C6,       bocznikowanie katod
                              C102, C106
 4 szt   100n/630V PP 5%      C3, C7,       sprzęgające (polipropylen)
                              C103, C107
 2 szt   3n3  1% PP           C4, C104      RIAA (1% obowiązkowo)
 2 szt   9n62 1% PP           C5, C105      RIAA; złożyć: 8n2 + 1n2 + 220p
                                            (równolegle, wszystkie 1%)
 2 szt   2u2/400V PP 5%       C8, C108      wyjściowe

KONDENSATORY — zasilacz
--------------------------------------------------------------------------------
 1 szt   47u/500V el. ±20%    C9            PIERWSZY po EZ81 — max 50 uF, limit
                                            lampy! Nie zwiększać.
 1 szt   100u/500V el. ±20%   C10           za dławikiem (B+3)
         (C9+C10 opcjonalnie jako kubek wielosekcyjny 50+100/500 V na płycie
          górnej, obejma z przekładką izolacyjną)
 4 szt   47u/400V el. ±20%    C12, C13,     filtry B+ per kanał
                              C112, C113
 1 szt   22u/100V el. ±20%    C17           elewacja żarzenia
 1 szt   100n/630V PP 10%     C18           ground breaker
 1 szt   100n/630V PP 10%     C21           snubber cewki K1

ŻARZENIE Z BATERII
--------------------------------------------------------------------------------
 1 szt   akumulator AGM/żel   BT1           6 V / 10–12 Ah (np. typ "UPS/alarm");
                                            TYLKO szczelny AGM lub żel!
 1 szt   bezpiecznik 2 A      F2            + oprawka; montaż BEZPOŚREDNIO przy
         zwłoczny                           zacisku baterii
 1 szt   obejma/rama baterii  —             sztywne skręcenie z dnem obudowy
 1 szt   ładowarka buforowa   —             ZEWNĘTRZNA, 6 V AGM, etapowa z trybem
                                            float 6,75–6,9 V (nie wchodzi w BOM
                                            urządzenia — krzem zostaje na półce)

AUTOMATYKA / STEROWANIE
--------------------------------------------------------------------------------
 1 szt   przekaźnik DPDT      K1            cewka 230 V AC (np. Finder 40.52,
                                            Relpol R2), styki min. 250 V /
                                            zdolność łączenia DC! gniazdo+zatrzask
 1 szt   wyłącznik dźwigniowy SW1           DPST/DPDT 250 V AC 3 A, metalowa
         sieciowy                           dźwignia (front)
 1 szt   przełącznik          SW2           DPDT 6 A, dźwigniowy (front);
         PRACA/ŁADOWANIE                    przełącza baterię: lampy / gniazdo J6
 1 szt   neonówka NE-2        NE1           + oprawka "jewel" bursztynowa (front)
 1 szt   woltomierz wychyłowy M1            zakres ~8 V DC (lub 100 uA + R30);
                                            zaznaczyć strefę 6,0–6,4 V (front)

ZŁĄCZA / MECHANIKA / SIEĆ
--------------------------------------------------------------------------------
 4 szt   gniazdo RCA          J1–J4         izolowane od chassis! (podkładki)
 1 szt   gniazdo IEC C14      J5            z szufladką bezpiecznika
 1 szt   bezpiecznik T500mA   F1            5×20, zwłoczny (w L, przed SW1)
 1 szt   złącze/gniazdo       J6            ładowanie 6 V (tylna ścianka);
         zaciskowe 2-pin                    biegunowość opisać na panelu!
 1 szt   zacisk masy          —             śruba radełkowana (masa gramofonu
         gramofonu                          → GND, nie chassis)
 —       przewód żarzenia     —             skręcona para, min. 1 mm2 (0,9 A)
 —       turret board,        —             wg ustaleń montażowych
         tulejki, dystanse                  (docs/PROJEKT-RIAA.md)

OSWIETLENIE LAMP (opcja dekoracyjna)
--------------------------------------------------------------------------------
 3 szt   zarowka miniaturowa  LA1-LA3       T1-1/4 / E5 lub E10, 6,3 V / 0,1 A;
                                            pod podstawkami lamp audio (przez
                                            otwor po srodkowym styku "shield")
 3 szt   oprawka E5/E10       —             montaz pod podstawka
 1 szt   rezystor drutowy     R35           0-22R / 10 W, regulowany (z obejma/
         regulowany                         suwakiem); szeregowo, ustawienie
                                            jasnosci OD SRODKA (raz, na stale)
 1 szt   wylacznik SPST       SW3           tylna scianka: OSWIETLENIE ON/OFF
 —       przewod: skretka     —             ekran do GND TYLKO z jednej strony
         w ekranie                          (od zasilacza); trasa po katach,
                                            z dala od wejsc
 Zasilanie: rev E -> odczep 6,3 V AC trafo (izolowany od DC zarzenia).
 Rev P -> uzwojenie 6,3 V EZ81, ALE WARUNEK: koniec uzwojenia dowiazac
 do GND zamiast do katody (Vhk EZ81 = -300 V, w limicie 500 V) — inaczej
 okablowanie oswietlenia siedzi na +300 V!
 Montaz podstawek pod kominek+poswiate: otwor w plycie 26-28 mm (wiekszy
 niz banka), podstawka POD plyta na tulejkach 5-8 mm -> pierscieniowa
 szczelina wokol szkla (powietrze + swiatlo). Pierscien ozdobny maskuje
 krawedz otworu.

UWAGI KOŃCOWE
--------------------------------------------------------------------------------
1. Ground breaker w tym wariancie BEZ diod (10R || 100n) — patrz notka na
   schemacie; alternatywa vintage: masa na sztywno do chassis przy wejściach.
2. Wszystkie elementy przy B+ : napięcia robocze jak w liście (400/500/630 V) —
   nie schodzić niżej.
3. Tolerancje: 1% tam, gdzie wartość ustala punkt pracy lub korekcję
   (RIAA: R5/R6, C4/C5 — obowiązkowo; katody i anody — dla powtarzalności
   kanałów); 5% wystarcza dla grid stopperów, upływowych, dropperów
   i bleederów; elektrolity ±20% (taka jest ich natura — wartości filtrów
   mają duży zapas). Elementy RIAA kupić po kilka sztuk i sparować
   miernikiem L/R.
4. Napięcia do ~330 V DC. Przed pracą: odczekać na rozładowanie (K1/R24 +
   bleedery) i SPRAWDZIĆ woltomierzem każdą sekcję (<50 V).
================================================================================

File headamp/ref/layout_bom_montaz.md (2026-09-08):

# Montaż powietrzny — przydział elementów toru audio (listwy vs nóżki lamp)

Uzupełnienie do `headamp/ref/layout_top.svg`/`.png` (propozycja rozmieszczenia
w obudowie, 2026-09-08). Montaż **powietrzny** (bez PCB w torze audio):
część elementów dolutowana wprost do nóżek podstawek lampowych, część na
listwach lutowniczych pod górną płytą (patrz rysunek). Zasilacz — patrz
osobno `docs/PROJEKT-HEADAMP.md` (strefa zarezerwowana, decyzja PCB vs
powietrznie otwarta).

Numeracja jak w `headamp/gen.py`/schemacie: kanał L = refy bazowe (R1..R9,
C1..C6, U1 unit A, U2, T1), kanał P = te same refy **+200** (R201..R209,
C201..C206, U1 unit B, U202, T201) — identyczna topologia i przydział
montażowy, lustrzanie.

## Numery pinów (referencja)

- **ECC82** (`Valve:ECC81`, Value="ECC82"): unit A (driver kanału L) — grid=7,
  anoda=6, katoda=8; unit B (driver kanału P) — grid=2, anoda=1, katoda=3;
  żarzenie (unit F, wspólne dla obu sekcji) — piny 4 i 5 (końce), pin 9
  (odczep środkowy).
- **EL84**: grid1 (sterująca) = pin 2, katoda/g3 (zwarte) = pin 3, anoda =
  pin 7, grid2 (ekranująca) = pin 9; żarzenie = piny 4/5.

## Na nóżkach podstawek (bez listwy — montaż bezpośredni)

| Element | Miejsce | Uzasadnienie |
|---|---|---|
| R2 (1k, kanał L) / R202 (P) | między pinem 7 U1 unit A (grid, kanał L) a końcówką C1 — analogicznie R202 między pinem 2 U1 unit B a C201 | grid stopper tuż przy siatce lampy — minimalna indukcyjność/pojemność montażowa doprowadzenia do siatki (krytyczne dla stabilności WCz) |
| C1 (220n) / C201 | dolutowany do wolnej końcówki R2/R202 (patrz wyżej), drugi koniec do wypru RV1 | sprzęgający wejściowy — wisi bezpośrednio na nóżce grid-stoppera, brak dodatkowego punktu podparcia |
| **R1 (470k, grid leak drivera) / R201** | **na nóżce R2/C1 (węzeł siatki U1, za C1) → GND najbliższej listwy** — fizycznie na listwie A (przy wejściu siatki) albo wprost z nóżki R2/C1 do szyny masy, **NIE „między A i B"** (poprawka 2026-09-08: wcześniejszy zapis błędnie umieszczał R1 na trasie sprzęgacza driver→EL84 — R1 elektrycznie siedzi na węźle siatki ECC82, nie ma nic wspólnego z sygnałem po stronie EL84) | grid leak wejściowy — musi wisieć na tym samym węźle co grid stopper R2/C1, drugi koniec możliwie krótko do masy |
| R9 (100R, zwora triodowa) / R209 | między pinami 7 (anoda) i 9 (g2) EL84 U2/U202 | zwora g2→a definiująca pracę triodową — musi mieć minimalną długość przewodu (ryzyko oscylacji UHF przy dłuższych odcinkach) |
| R7 (1k) / R207 | jedna nóżka na pinie 2 (g1) EL84 U2/U202, druga do węzła sprzęgającego (patrz "między A i B" niżej) | grid stopper EL84 — jak R2, minimalna indukcyjność przy siatce |

## Listwa A (8–10 punktów, przy podstawce ECC82 U1) — wspólna dla obu kanałów, refy L i P obok siebie

| Punkt | Elementy | Węzeł |
|---|---|---|
| A1 | R3 (1k5) + C2 (1µ/25V) + C3 (100µ/25V, przez SW2) | katoda drivera (bias RC + obejście "wokal do przodu") |
| A2 | R4 (47k/2W) / R5 (10k/2W) + C4 (47µ/350V) | anoda drivera + odsprzęganie B+ drivera |
| A3 | R201 wersja kanału P (lustro A1) | jw., kanał P |
| A4 | R204/R205 + C204 (lustro A2) | jw., kanał P |

Uzasadnienie: węzły RC katodowe i odsprzęganie B+ na listwach (nie na
nóżkach) — łatwa wymiana/serwis, dostęp bez demontażu lampy; nie są
krytyczne pod względem długości przewodu (niska impedancja węzła katody,
niskie częstotliwości odsprzęgania).

## Między listwą A i listwą B_L/B_P (elementy sprzęgające, fizycznie pomiędzy)

**Poprawka 2026-09-08:** ta sekcja zawiera teraz tylko R6/R206 i C5/C205 — R1/R201
(grid leak *wejściowy*, strona ECC82) został z niej usunięty, patrz tabela
"Na nóżkach podstawek" wyżej (R1 siedzi na węźle siatki drivera, nie na trasie
sprzęgacza driver→EL84).

| Element | Uzasadnienie |
|---|---|
| R6 (470k, grid leak EL84) / R206 | elektrycznie w tym samym węźle co C5 (wyjście sprzęgacza, strona siatki EL84) — fizycznie musi sięgać od C5 (przy A) do GND (przy B) |
| C5 (100n/400V, sprzęgający driver→EL84) / C205 | łączy anodę drivera (listwa A) z grid-stopperem R7 przy EL84 — z definicji rozpięty między obiema strefami |

## Listwa B_L / B_P (5–6 punktów, przy podstawce EL84, osobna dla każdego kanału)

| Punkt | Elementy | Węzeł |
|---|---|---|
| B1 | R8 (270R/5W) + C6 (470µ/25V) | katoda EL84 (bias RC) |
| B2 | daleki koniec R6 (patrz wyżej) | grid leak EL84 → GND |
| B3 | daleki koniec R7 (patrz wyżej) | grid stopper EL84 → węzeł sprzęgający |

Kanał P: listwa B_P analogicznie z R208+C206 (punkt B1), R206/R207 (B2/B3).

## Listwa D (wyjściowa, przy jacku J403) — opcjonalna

Wtórne uzwojenia T1/T201 → jack 6,3 mm J403 (piny T/R/S) mogą iść
bezpośrednio (krótkie przewody, niska impedancja 80 Ω — długość przewodu
nieistotna). Listwa D przewidziana jako punkt pośredni tylko jeśli
mechanicznie wygodniej (np. odciążenie naprężeń przewodu do gniazda).

## Elektrolity wysokonapięciowe — z dala od gorących EL84

C4/C204 (47µ/**350V**, odsprzęganie B+ drivera) siedzą na **listwie A**
(przy ECC82), nie przy EL84: driver pracuje chłodniej niż końcówka mocy
(EL84 ~285 V/29 mA, 8,2 W rozpraszane w bańce), więc kondensator o
najwyższym napięciu izolacji w torze audio (poza zasilaczem) jest
umieszczony jak najdalej od źródła ciepła — dłuższa żywotność elektrolitu.
C6/C206 (470µ/25V, katoda EL84) musi siedzieć blisko EL84 (funkcjonalnie,
niska impedancja katody) — niższe napięcie, mniejsze ryzyko degradacji
termicznej niż przy 350 V.

## Szyna masy, żarzenie, B+ — trasy (patrz rysunek)

- **Szyna masy** (drut Ø1,5–2 mm): łamana ortogonalna wzdłuż rzędu listw
  (B_L→B_P poziomo, odczep pionowy do A), jeden punkt do chassis przez
  ground breaker (R309/D310/D311/C309) przy IEC — zgodnie z
  `docs/PROJEKT-HEADAMP.md` (jedyny styk GND↔PE). **Poprawka 2026-09-08
  (runda 2):** IEC J1+F1 przeniesione ze ściany tylnej na ścianę lewą
  (front, x=0, y≈6–54) — ground breaker fizycznie bliżej tego nowego
  miejsca, korytarz odgałęzienia od listwy B_L przesunięty z x≈98 na
  x≈101 mm (patrz `docs/PROJEKT-HEADAMP.md`).
- **Żarzenie** (skręcona para, 6,3 V DC z LD1085/U301): z uzwojenia T301
  wzdłuż lewej/tylnej krawędzi, korytarzem x≈101 mm, rzędem EL84 (U2→U202)
  do każdej podstawki — ECC82 piny 4+5 (+), pin 9 (−, odczep środkowy,
  redukcja przydźwięku); EL84 pin 4 (+), pin 5 (−). **Poprawka 2026-09-08
  (runda 2):** odgałęzienie do ECC82 (U1) idzie teraz prosto w dół ze
  środka między EL84 (x=178, nie od strony RV1/wejścia jak poprzednio) —
  skręcona para DC z dala od RV1/wejścia sygnału.
- **B+ (+300 V)**: przewód ze strefy zasilania do listw B_L/B_P i A —
  trasa poprowadzona z dala od toru wejściowego (crossfeed/RV1/RCA), aby
  uniknąć sprzężenia HV z sygnałem małej amplitudy.
- **Sygnał wejściowy**: RCA (tył, środek-prawo, J401/J402) → wzdłuż prawej
  krawędzi obudowy → listwa C (crossfeed, R401–R406/C401–C404; **przesunięta
  na prawo od RV1**, między RV1 a prawą ścianą — poprawka 2026-09-08, żeby
  sygnał z RCA nie krzyżował frontu) → RV1 → ECC82 (krótki tor siatkowy,
  patrz R2/R202 wyżej). Kabel ekranowany na całej trasie RCA→listwa C→RV1.

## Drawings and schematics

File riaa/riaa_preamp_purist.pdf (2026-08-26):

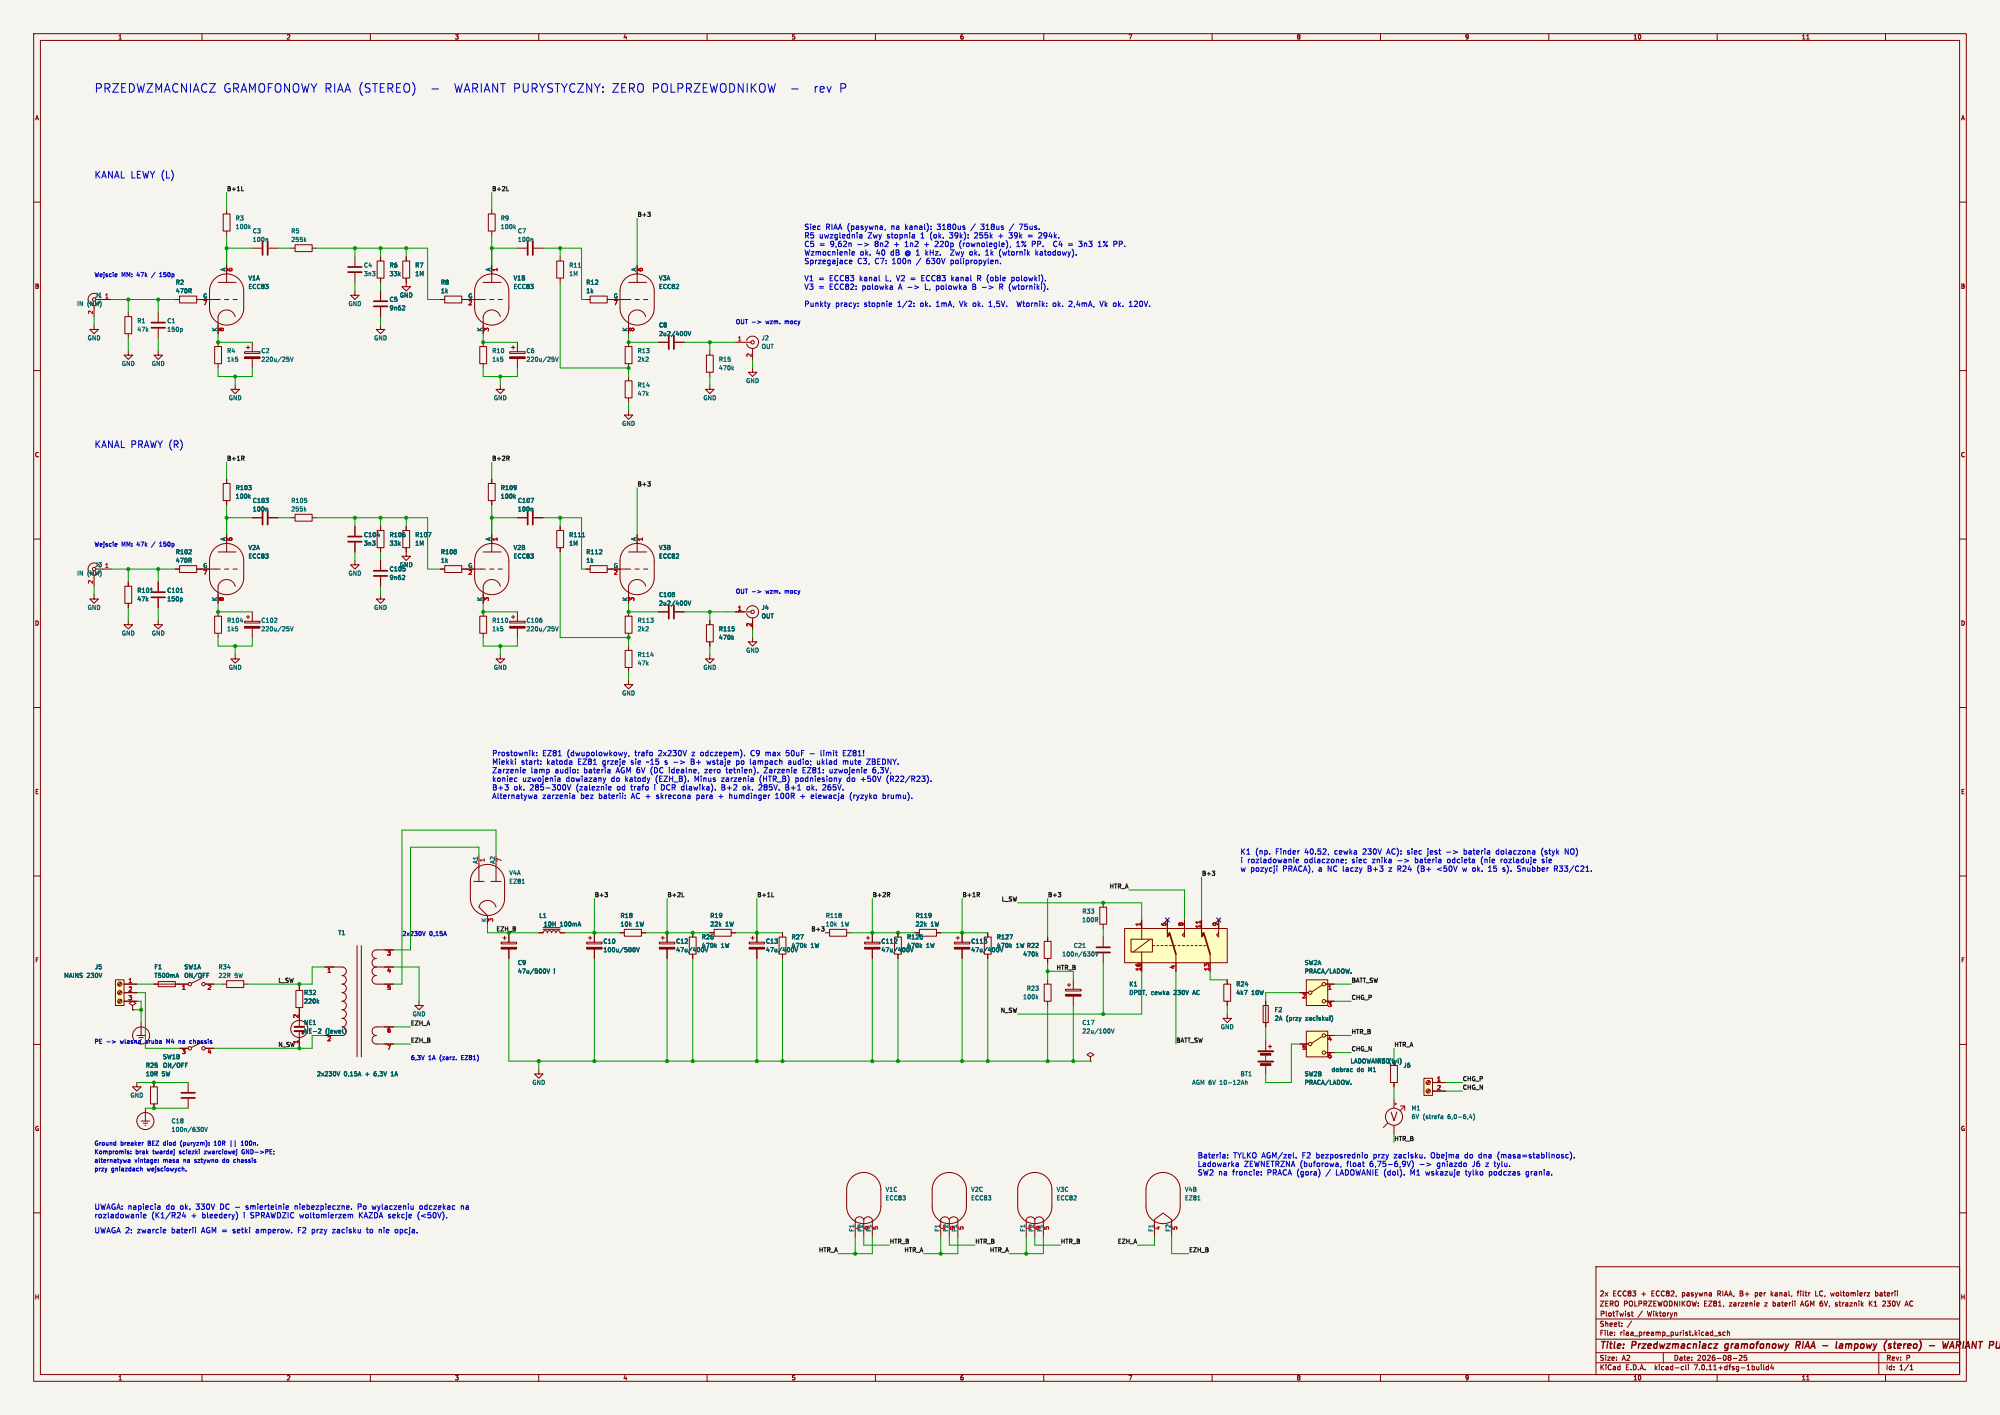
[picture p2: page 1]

SW2 na froncie: PRACA (gora) / LADOWANIE (dol). M1 wskazuje tylko podczas grania.

File: riaa_preamp_purist.kicad_sch Sheet: / PlotTwist / Wiktoryn

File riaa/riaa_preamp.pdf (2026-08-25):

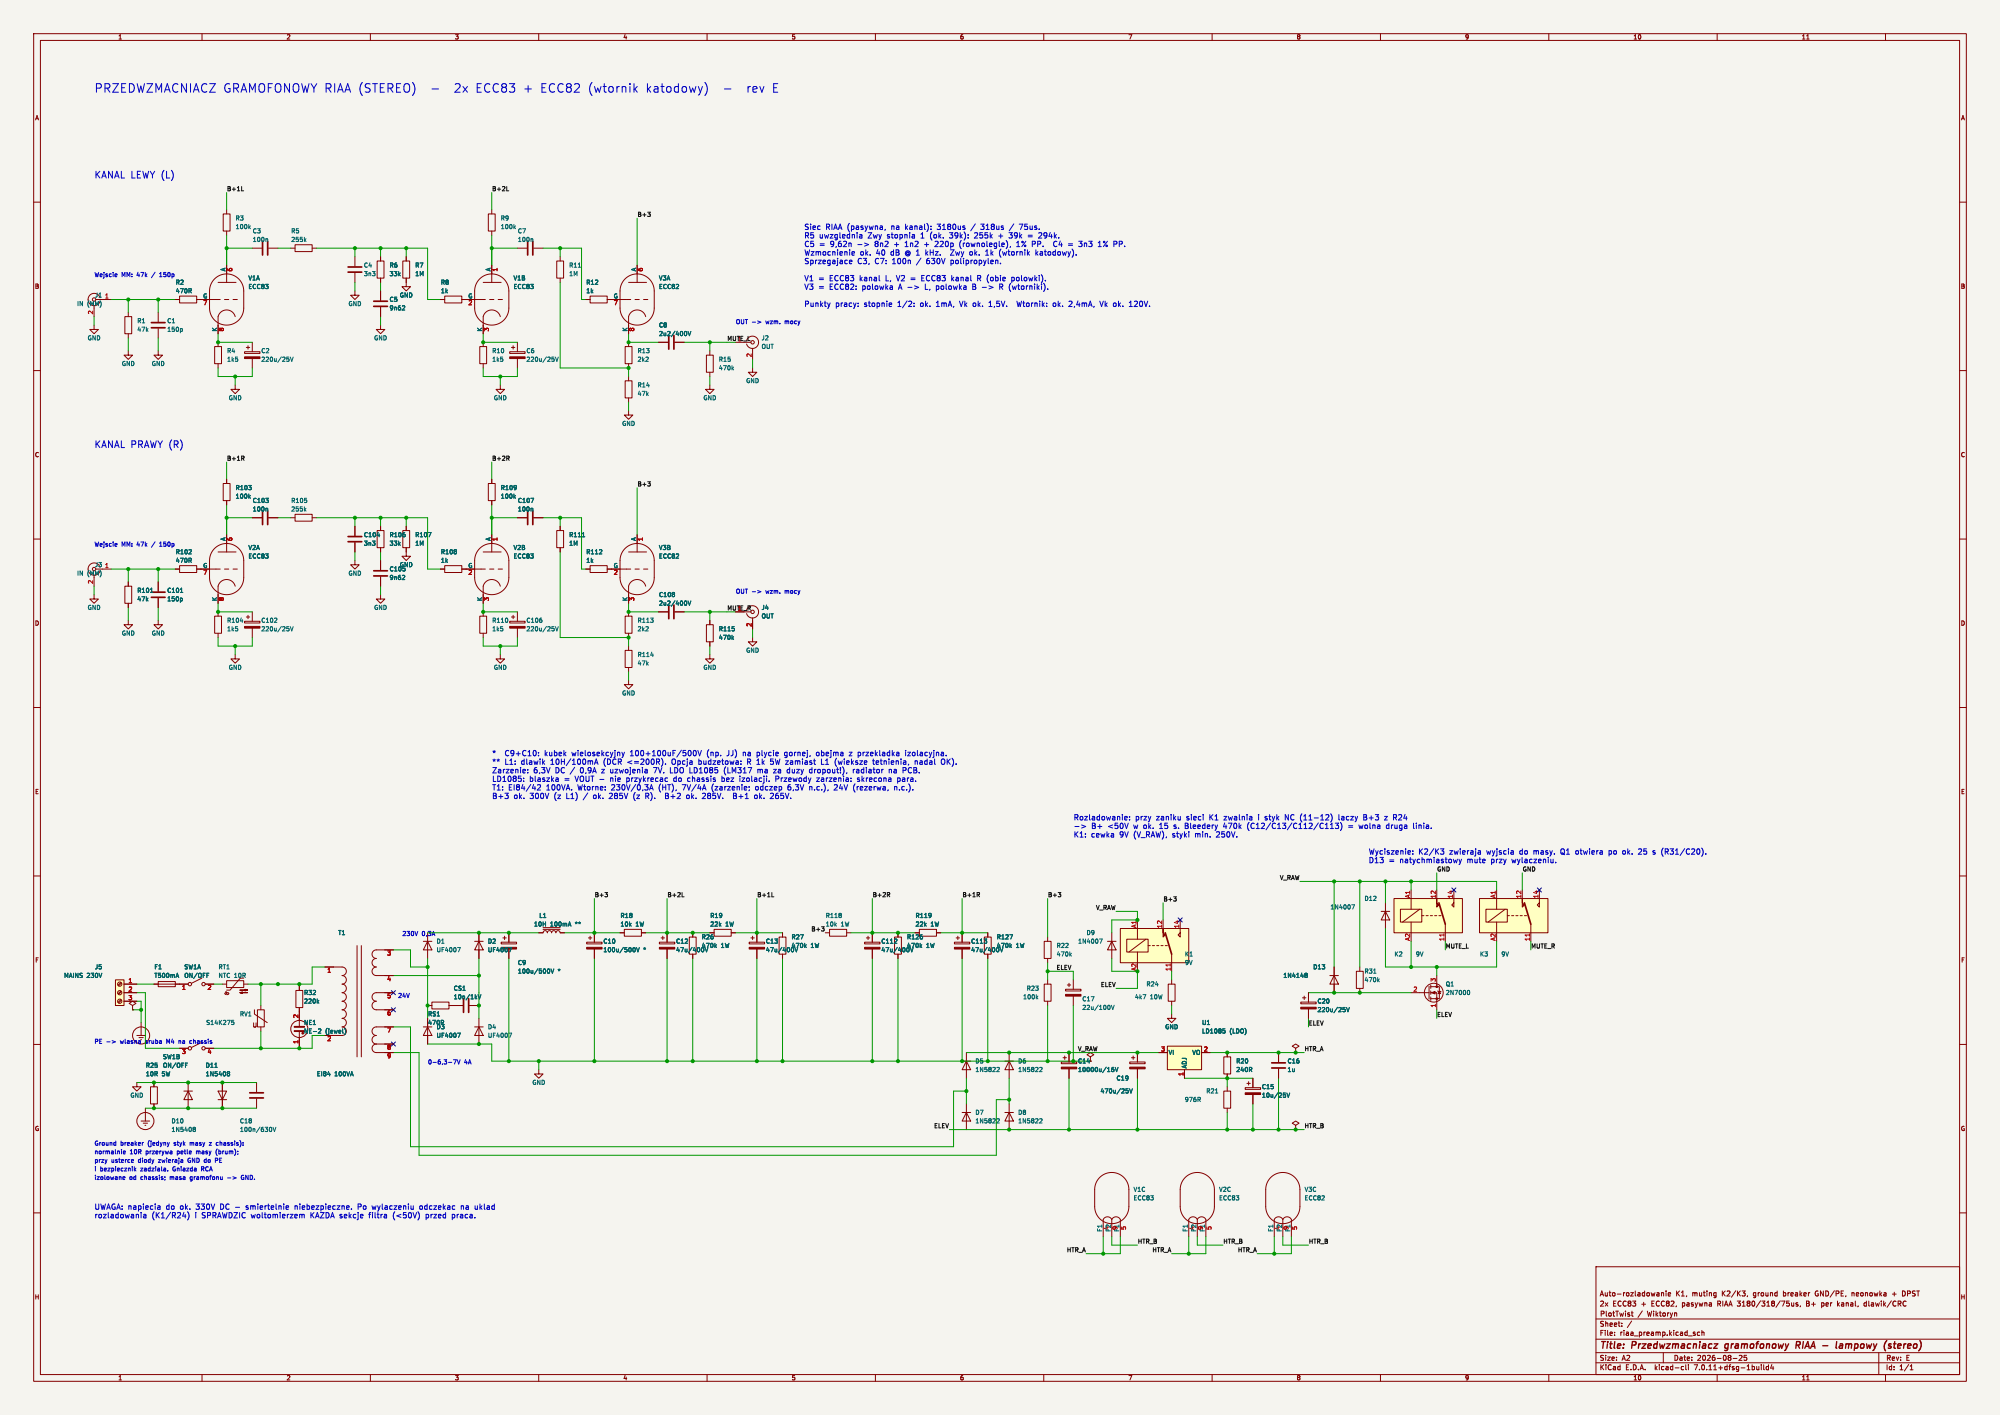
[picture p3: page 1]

Siec RIAA (pasywna, na kanal): 3180us / 318us / 75us.

V1 = ECC83 kanal L, V2 = ECC83 kanal R (obie polowki).

Ground breaker (jedyny styk masy z chassis):
przy usterce diody zwieraja GND do PE

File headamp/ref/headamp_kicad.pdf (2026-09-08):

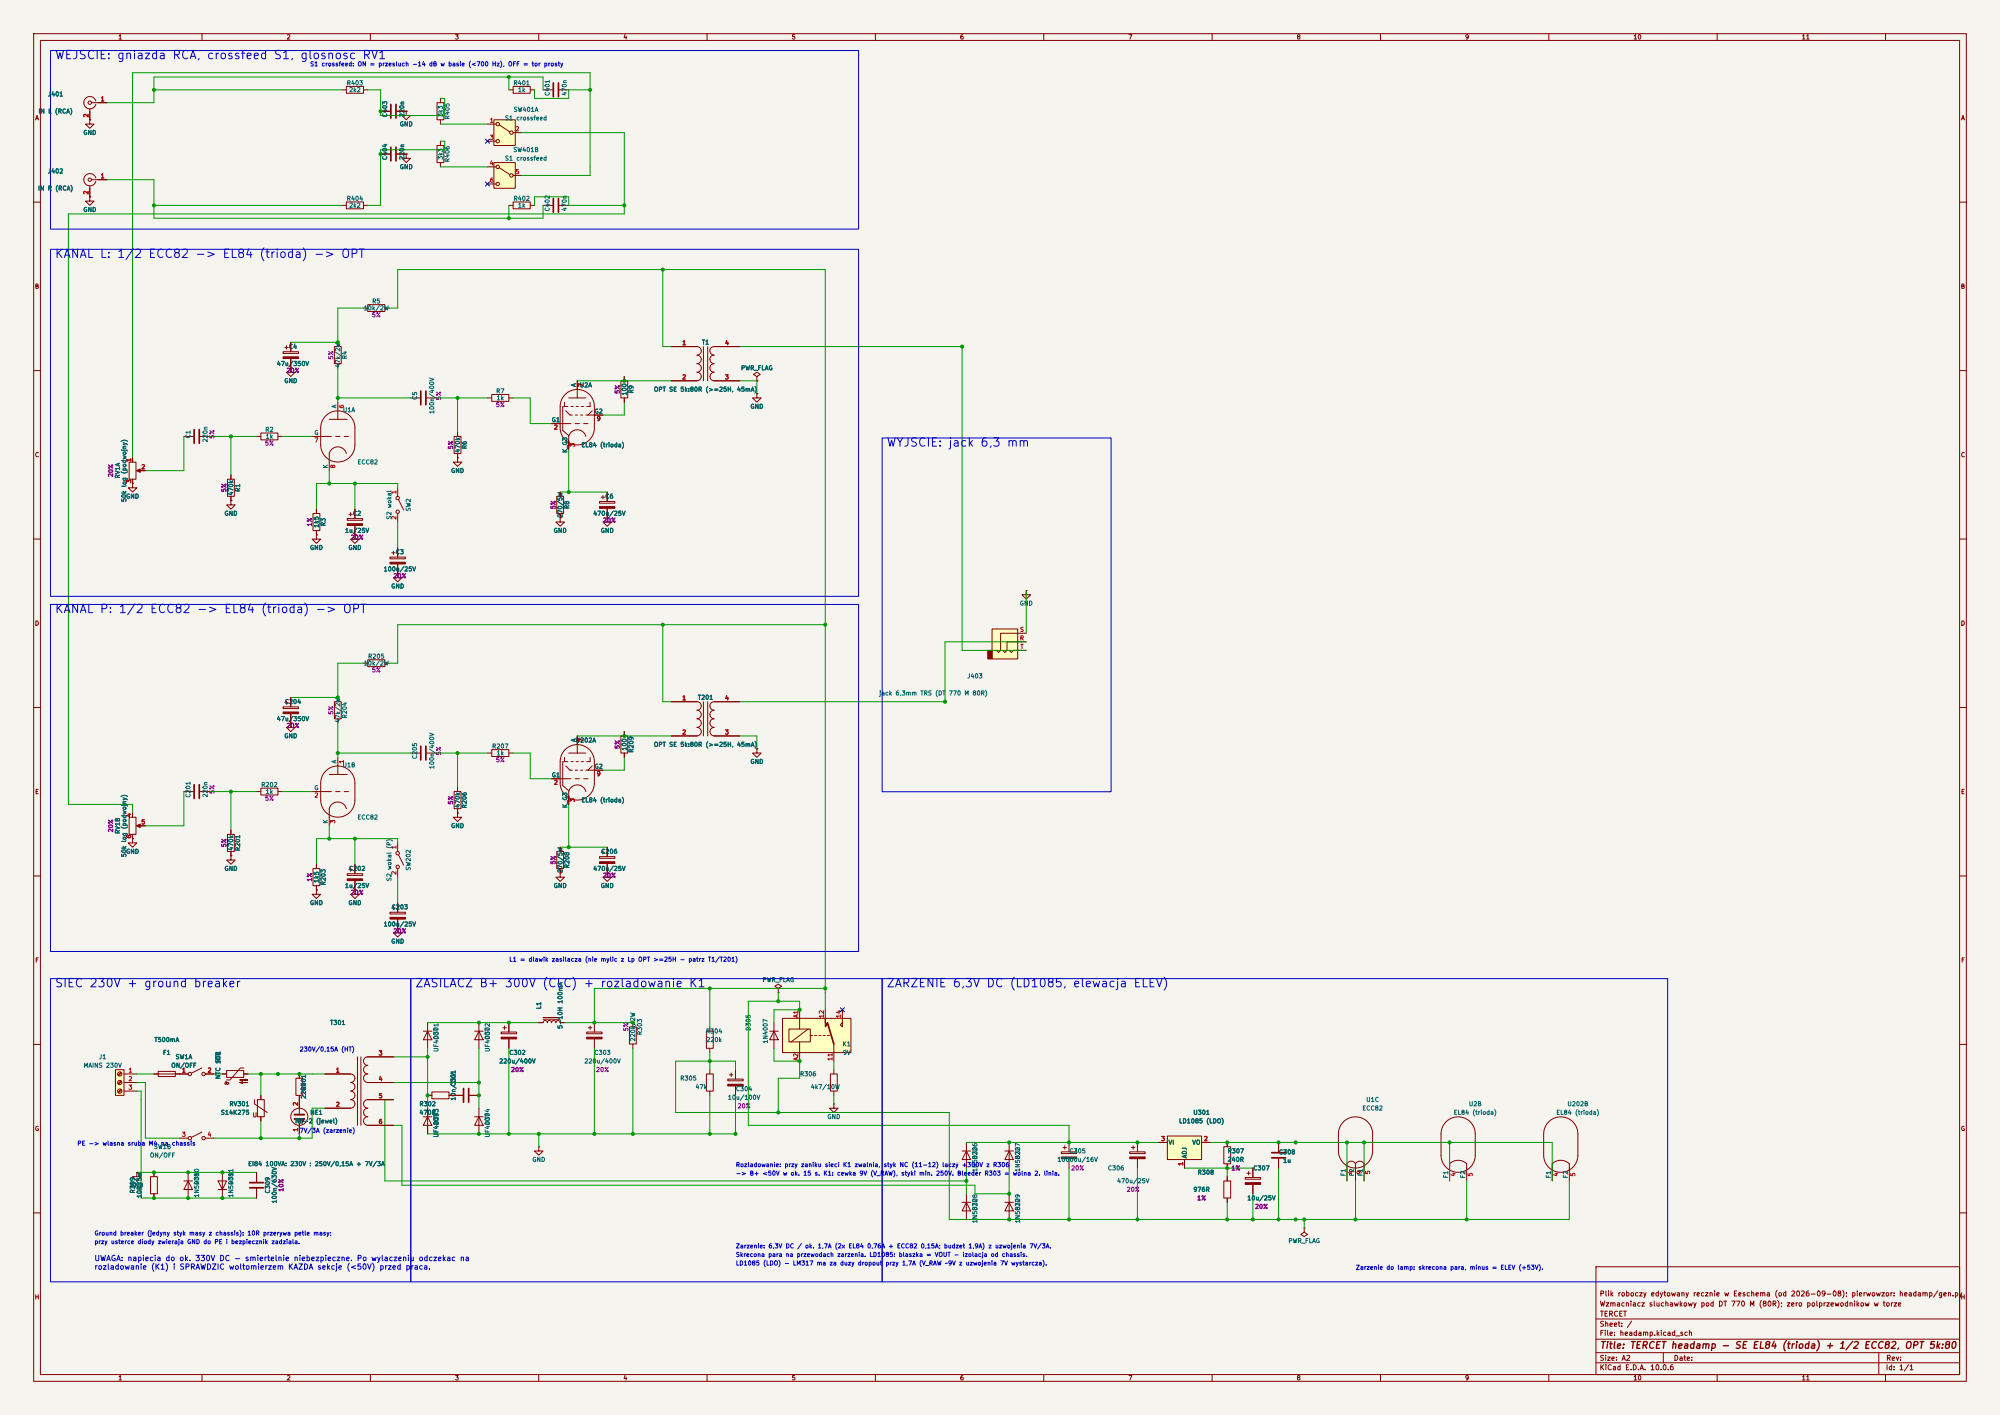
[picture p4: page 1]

WEJSCIE: gniazda RCA, crossfeed S1, glosnosc RV1 S1 crossfeed: ON = przesluch -14 dB w basie (<700 Hz), OFF = tor prosty

KANAL L: 1/2 ECC82 -> EL84 (trioda) -> OPT

WYJSCIE: jack 6,3 mm

L1 = dlawik zasilacza (nie mylic z Lp OPT >=25H - patrz T1/T201)

ZARZENIE 6,3V DC (LD1085, elewacja ELEV)

Ground breaker (jedyny styk masy z chassis): 10R przerywa petle masy; przy usterce diody zwieraja GND do PE i bezpiecznik zadziala. rozladowanie (K1) i SPRAWDZIC woltomierzem KAZDA sekcje (<50V) przed praca.

UWAGA: napiecia do ok. 330V DC - smiertelnie niebezpieczne. Po wylaczeniu odczekac na

Zarzenie do lamp: skrecona para, minus = ELEV (+53V).

Wzmacniacz sluchawkowy pod DT 770 M (80R); zero polprzewodnikow w torze
TERCET
Sheet: /
File: headamp.kicad_sch
Title: TERCET headamp - SE EL84 (trioda) + 1/2 ECC82, OPT 5k:80

Size: A2 | Rev:
KiCad E.D.A. 10.0.6 | Id: 1/1

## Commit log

2026-08-25 TERCET: struktura repo + RIAA rev E (schemat, generator, testy netlisty, dokumentacja)
    [riaa_preamp.kicad_sch]
2026-08-26 riaa: wariant purystyczny rev P - EZ81, zarzenie z baterii AGM, straznik K1 230V AC, woltomierz
    [riaa_preamp_purist.kicad_sch]
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2026-09-07 headamp: schemat kanalu L zbudowany przez Konnect (KiCad) - ECC82 + EL84 trioda + OPT, S2, ERC 0 bledow
    - U1A (1/2 ECC82) wspolna katoda, R3/C2 + S2/C3 (wokal do przodu)
    - U2 EL84 ze zwora triodowa R9 100R, R8/C6, T1 SE 5k:80
    - zarzenie: HEAT_A/HEAT_B (6,3V DC z common/), PWR_FLAG
    - ERC: 0 bledow; ostrzezenia oczekiwane (wolny unit B ECC82 = kanal P, IN_L/OUT_L)
    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
    [headamp.kicad_sch]
2026-09-07 headamp: tolerancje elementow pasywnych na schemacie (pole Tolerance)
    Rezystory 5% (R3 1%), folie 5%, elektrolity i RV1 20%. Pola dodane przez
    Konnect, widocznosc/pozycja skryptem (Konnect tego nie obsluguje). ERC 0.
    [headamp.kicad_sch]
2026-09-07 headamp: generator schematu (gen.py + symlib.py + check.py), port kanalu L 1:1
    Schemat kanalu L (audio + zarzenie) odtworzony jako kod (wzor riaa/gen.py)
    z commitu b7d6cc9 (ERC 0 bledow). Netlista wygenerowanego pliku jest
    rownowazna netliscie zrodlowej (te same partycje pin-do-pin, 18 sieci).
    ERC po porcie: 5 ostrzezen (wolny unit B ECC82, dyndajace IN_L/OUT_L) -
    identycznie jak przed portem. check.py z asercjami netlisty (wzor
    riaa/check.py). headamp/headamp.kicad_sch jest teraz zrodlem
    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
    [headamp.kicad_sch]
2026-09-07 headamp: gen.py - deterministyczne uuid (uuid5), regeneracja idempotentna
    Kazdy element (symbol, pin, wire, junction, label, glabel, text, no_connect)
    dostaje uuid5(NAMESPACE, klucz) zamiast losowego uuid4 - dwa uruchomienia
    gen.py daja identyczny plik. Netlista i ERC bez zmian (check.py OK,
    ERC 0 bledow, 5 oczekiwanych ostrzezen: wolny unit B ECC82 x3, wiszace
    IN_L/OUT_L x2).
    [headamp.kicad_sch]
2026-09-07 headamp: kanal P (unit B ECC82 + drugi EL84 + drugi OPT + RV1 dual)
    Kanal prawy dodany jako parametryzowana funkcja chan() w gen.py -
    identyczna geometria kanalu L, przesunieta o 105,41 mm w Y (siatka
    1,27mm), refy +200 (R201-R209/C201-C206/SW202/T201/U202), U1 unit B
    (driver, ta sama lampa ECC82). RV1 zmieniony na potencjometr podwojny
    (Device:R_Potentiometer_Dual_Separate) - unit1=L, unit2=P (DECYZJA,
    brak wczesniejszej w docs). Etykiety IN_R/OUT_R, wspolne HEAT_A/HEAT_B
    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
    [headamp.kicad_sch]
2026-09-07 headamp: zasilacz (B+ CLC, zarzenie LD1085, K1, ground breaker)
    Sekcja zasilacza dodana na tym samym arkuszu, layout drutami (wzor
    riaa/gen.py), numeracja 3xx + wyjatki nazwane (F1,SW1,J1,RT1,RV301,
    NE1,T301,L1,K1,U301). Siec 230V (bezpiecznik, DPST, NTC, warystor +
    neonowka) -> Transformer_1P_2S (230V:250V/0,15A+7V/3A) -> mostek
    UF4007 + snubber -> CLC (220u/L1/220u) -> wspolny +300V (bez podzialu
    per-kanal jak w RIAA) + bleeder 220k/2W. Elewacja 220k/47k + 10u ->
    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
    [headamp.kicad_sch]
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2026-09-07 headamp: Etap 6 - estetyka schematu (pola ref/value/tolerance)
    Przeglad renderu (Konnect render_schematic_png) wykazal liczne
    nakladajace sie pola Reference/Value/Tolerance w nowych sekcjach
    (kanal P, zasilacz). Poprawki w gen.py:
    - domyslne polozenie pol (gdy 'fields' nie podaje jawnie) rozszerzone
    o trzeci wiersz (Tolerance) zamiast zgadywania z vpos - usuwa
    nachodzenie value/tolerance na diodach mostka i duzych kondensatorach
    (C305 10000u, C306, C307, C308, R307, R308).
    - jawne fields dla C302/C303/R303/C304/L1 (tolerancja/wartosc rozsuniete
    od kolumny R303 i od dlugiego opisu L1 - skrocony do "5-10H 100mA",
    szczegol w osobnym text()).
    - F1 przesuniety nad linie LR (nie kolidowa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
    [headamp.kicad_sch]
2026-09-08 headamp: layout w ramkach modulow, polaczenia drutami (hybryda), zarzenie jako etykiety
    Etap A (DECYZJE 2026-09-08, docs/PROJEKT-HEADAMP.md nastepuje w Etapie C):
    - B+ (+300V): zamiast global_label - realne druty + wspolna magistrala
    pionowa BUS_X=245,11mm laczaca oba kanaly (korytarze nad modulami,
    y=80,01/185,42) z zasilaczem (CLC, R304/elewacja, K1). GND/PE zostaja
    symbolami power (bez zmian).
    - Zarniki lamp NIE SA RYSOWANE: usuniete unity grzania ECC82 (U1 unit3),
    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
    [headamp.kicad_sch]
2026-09-08 headamp: crossfeed S1 (DPDT) + gniazda RCA/jack
    Etap B (DECYZJE 2026-09-08):
    - Crossfeed S1 (SW401, Switch:SW_DPDT_x2) miedzy gniazdami wejsciowymi a
    RV1. Topologia i wartosci - ZRODLO PRAWDY: headamp/sim/crossfeed.cir
    (bez przelacznika w cir - modeluje pozycje "krzyzowy" zalaczona). Tor
    prosty R401||C401 (kanal L), R402||C402 (kanal P) ZAWSZE wpiety miedzy
    gniazdo a RV1 (bypass przelacznika); SW401 przelacza tylko doplyw
    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
    [headamp.kicad_sch]
2026-09-08 docs: headamp - layout hybrydowy, crossfeed, gniazda, zarzenie bez unitow
    Aktualizacja docs/PROJEKT-HEADAMP.md (sekcja "Decyzje - Etap 6"), CLAUDE.md
    i headamp/README.md po Etapach A-B: hybryda druty/GND-symbole, zarniki
    nierysowane (mapowanie pinow w tekscie na schemacie, ERC missing_unit x3
    oczekiwane), S1 przelaczany (tor prosty zawsze wpiety, przelacznik steruje
    tylko galezia krzyzowa), gniazda RCA/TRS (typy, numeracja 4xx), rozmiar
    arkusza A2 (uzasadnienie).
    Najwazniejsze: udokumentowane OTWARTE odkrycie z tego etapu - ERC ma
    formalnie 3 bledy missing_power_pin (U1/U2/U202, piny grzania typu
    power_in w bibliotece Valve) obok oczekiwanych ostrzezen. Brief zakladal
    same warningi; nie da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
2026-09-08 headamp: przeglad koncowy - poprawki pol ref/value w module wejsciowym i J403
    Etap D (przeglad PDF calosci + powiekszenia kazdego modulu):
    - WEJSCIE: R401-R406/C401-C404 dostaly wlasne pola ref_at/val_at (wzor z
    chan()) - domyslne pozycje nachodzily sie przy kilku blisko postawionych
    rezystorach/kondensatorach. J401/J402 (gniazda RCA) przesuniete tak, zeby
    etykieta miescila sie w ramce modulu (wczesniej wystawala poza lewa
    krawedz).
    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
    [headamp.kicad_sch]
2026-09-08 headamp: zarniki lamp drutami w bloku zarzenia (ERC 0 bledow), prad zarzenia 1,7A, kosmetyka arkusza
    Przywrocone (wariant a) unity grzania ECC82/EL84, rysowane realnymi
    drutami wewnatrz ramki ZARZENIE zamiast etykiet HEAT_A/HEAT_B - usuwa
    3 bledy missing_power_pin i 3 ostrzezenia missing_unit z ERC (teraz 0/0,
    takze multiple_net_names ELEV/HEAT_B znika). Poprawiony blad w tekscie
    na schemacie: prad zarzenia to ok. 1,7A (2x EL84 + ECC82), nie 0,3A.
    Zmniejszony PSU_DY (26,67mm z 76,2mm) zamyka pusty pas miedzy KANAL P
    a rzedem zasilacza; poszerzona ramka ZARZENIE pod trzy lampy. Dodane
    asercje netlisty w check.py po stronie zarnikow.
    [headamp.kicad_sch]
2026-09-08 headamp: crossfeed S1 przelacza galaz krzyzowa po stronie wyjscia (czysty tor prosty przy OFF) + sim
    Poprzednia topologia (S1 na wejsciu galezi krzyzowej) zostawiala R405/R406+
    C403/C404 jako obciazenie wyjsc toru prostego nawet przy S1 OFF - ugiecie
    basu ~1,4 dB (symulacja porownawcza w sim/crossfeed_sw.cir, wariant "OFF
    stara topologia"). Po przeniesieniu SW401 na wyjscie galezi krzyzowej (za
    R405/R406, przed wspolnym wezlem z torem prostym), pozycja OFF odcina cala
    galaz od wyjsc - odchylka od plaskiej ~0,17 dB (tylko C401/C402 w torze
    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
    [headamp.kicad_sch]
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
